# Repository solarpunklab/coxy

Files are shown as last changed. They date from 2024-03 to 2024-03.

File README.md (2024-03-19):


<div align="center">
<!-- ## SOLARPUNKLAB - CoXY -->
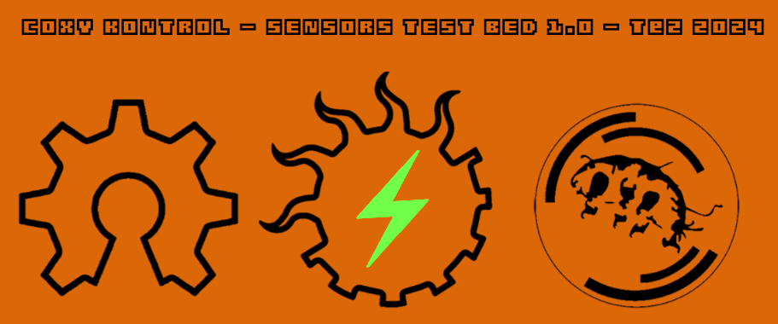
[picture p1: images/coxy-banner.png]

<!-- PROJECT LOGO -->

</div>

<br>

<div align="left" width = 90% id="contents">
<!-- TABLE OF CONTENTS -->
<details open>
  <summary style="background-color: #aaa;"><b>CONTENTS</b></summary>
  <ul>
	<li><a href="#about">About CoXY<br></a></li>
	<li><a href="#coxy-hardware">CoXY Hardware<br></a></li>
	<li><a href="#coxy-software">CoXY Sofwtare<br></a></li>
  </ul>
  </details>
</div>

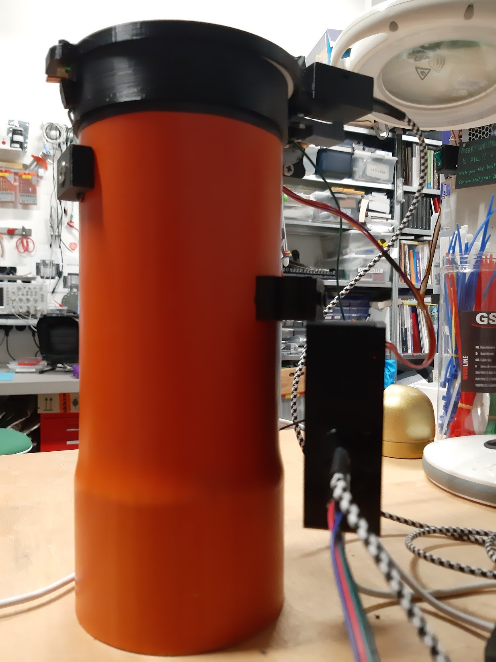
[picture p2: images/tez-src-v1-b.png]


<br><br><hr> <br><br>

<!-- >>>>>> TABLE ABOUT CoXY <<<<< -->
<table width = 90%>
<tr>
<td align = "justify" width = 90% colspan=2>
<p align="justify" id="about">
<b>ABOUT CoXY</b>
<br><br>
CoXY is a project by TeZ of 
<a href="http://solarpunklab.org">SOLARPUNK LAB</a> / 
<a href="http://hackteria.org">HACKTERIA</a> 
aimed at designing and experimenting a combined hardware and software platform that can function as a test bed for sensors' data monitoring/visualization and automation control, including motors, lights, switches and/or anything that can be driven by transistors. 
<br><br>
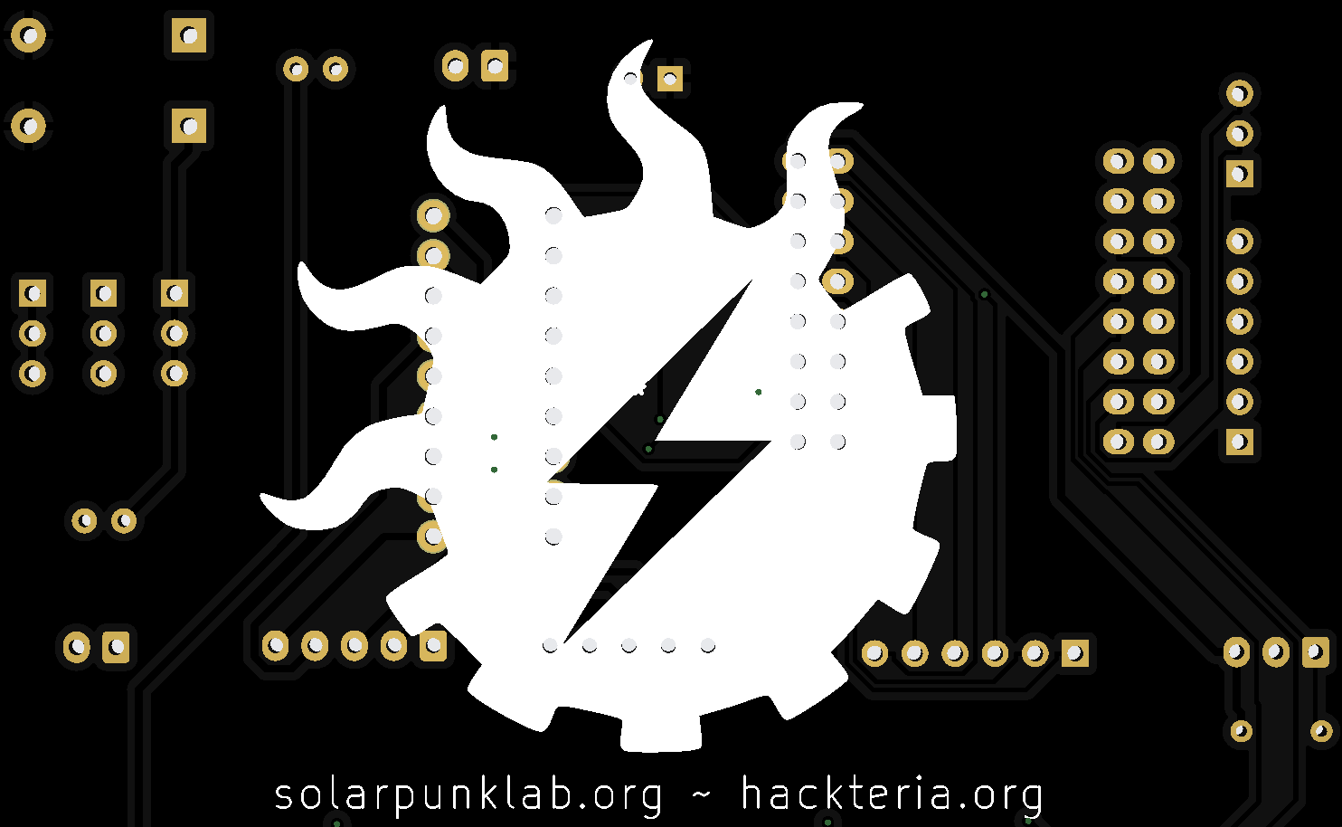
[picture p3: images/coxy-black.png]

<br><br>
The concept arose from the collaborative efforts of Marc Dusseiller Dusjagr  and Fernando Castro, both affiliated with HACKTERIA. Their inspiration stemmed from their involvement in the GOSH Open Hardware project, where they jointly explored the design and creation of a DIY platform for Soil Respiration Chamber(SRC). See <a href="https://hackteria.org/wiki/CO2_Soil_Respiration_Chamber">Hackteria Wiki</a> for an extended overview and documentation.
<br><br>
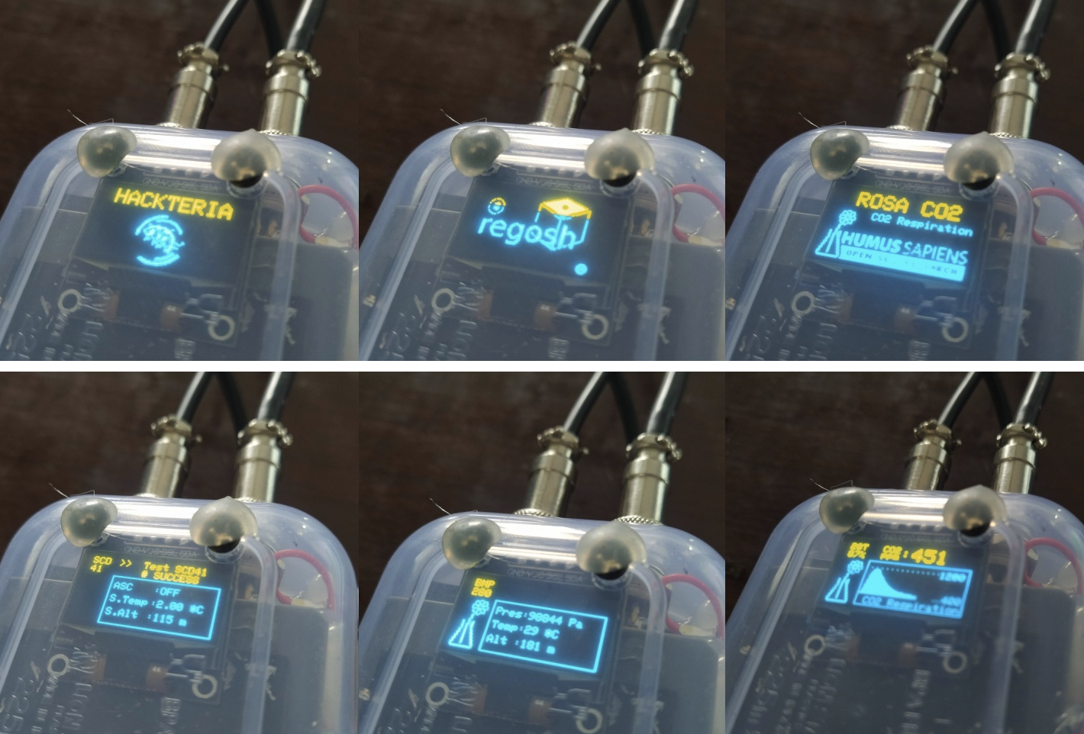
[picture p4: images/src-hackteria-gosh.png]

<br><br>
TeZ and Marc reconstructed a SRC prototype at Solarpunk Lab headquarters in Amsterdam. Subsequently, TeZ embarked on experimenting with an expanded version, aiming to incorporate local sensor data monitoring via WiFi/websockets technology and mechanical parts control using motors. 
<br><br>
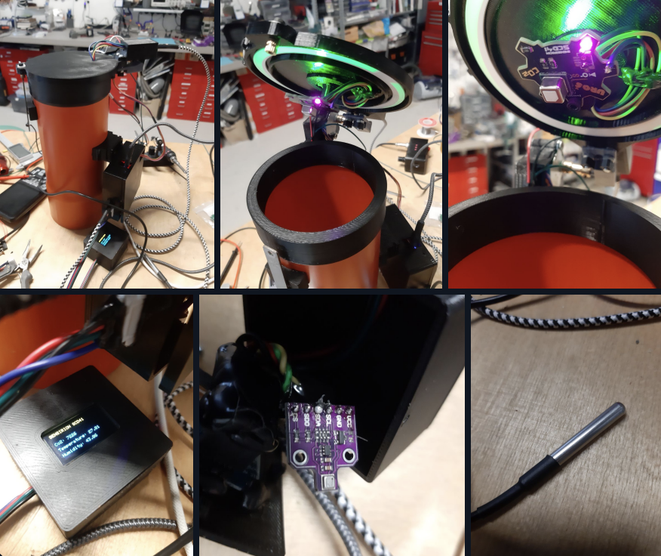
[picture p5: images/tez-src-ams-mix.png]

<br>
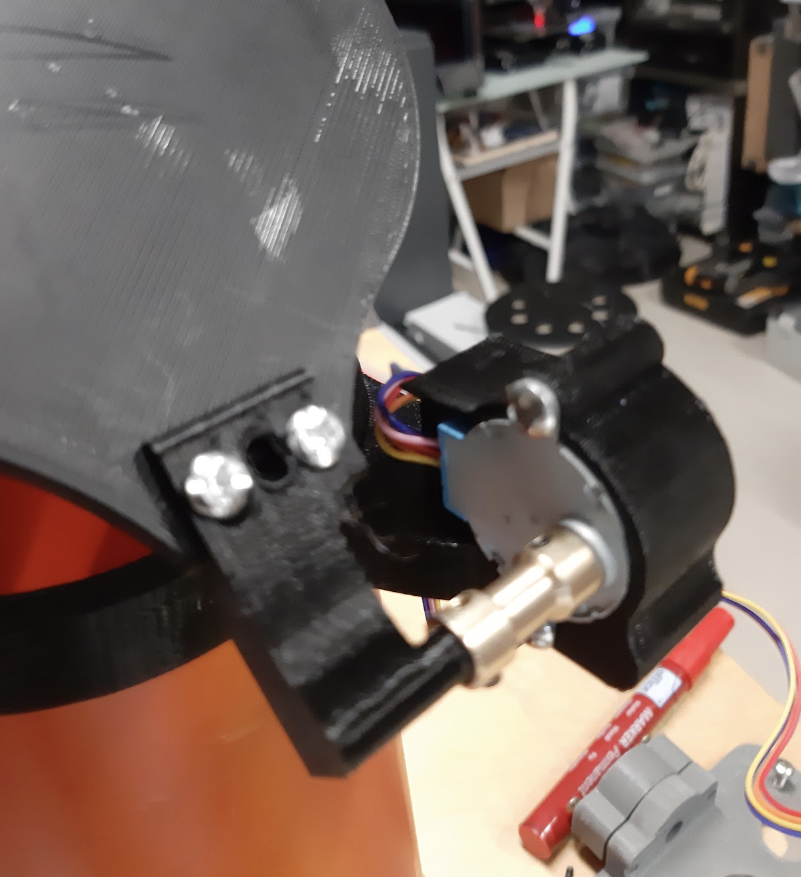
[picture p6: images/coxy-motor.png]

<br><br>
TeZ designed a printed circuit board (PCB) capable of seamlessly daisy-chaining up to five I2C devices. Additionally, it enables control over 8 channels of analog electrical signals via a transistor array IC. This is ideal to easily control the 2 coils of a 28byj-48 stepper motor with 4 channels. The PCB also features breakout options for additional ESP32 I/O pins and voltage supply.
<br><br>
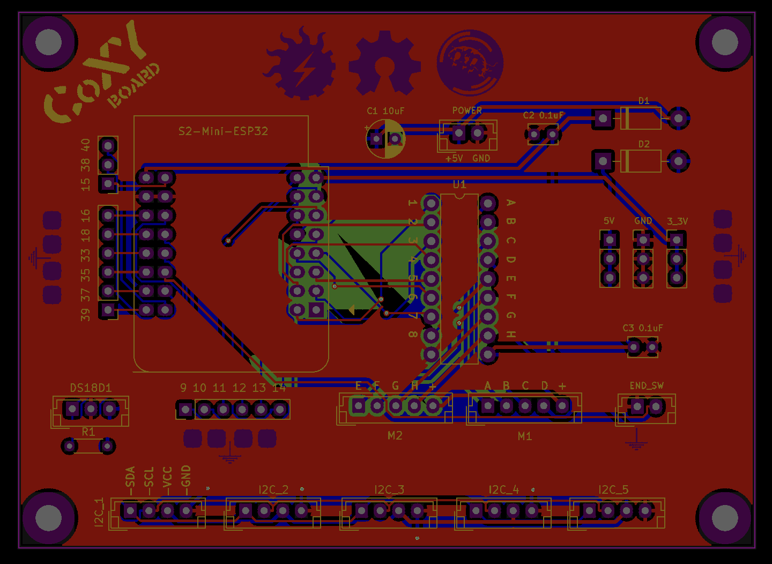
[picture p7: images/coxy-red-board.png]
</a>
This first version of the PCB is paired with a browser-based (hence cross-platform) software application, highly customizable and flexible.

<br><br>


<br><br>

<a href="#contents"></A>
<br>
</tr>
</table>

 <!-- >>>>>> TABLE CoXY HARDWARE <<<<< -->
<table width = 90%>
<tr>
<td align = "justify" width = 90% colspan=2>
<p align="justify" id="coxy-hardware">
<b>CoXY HARDWARE</b>
<br><br>
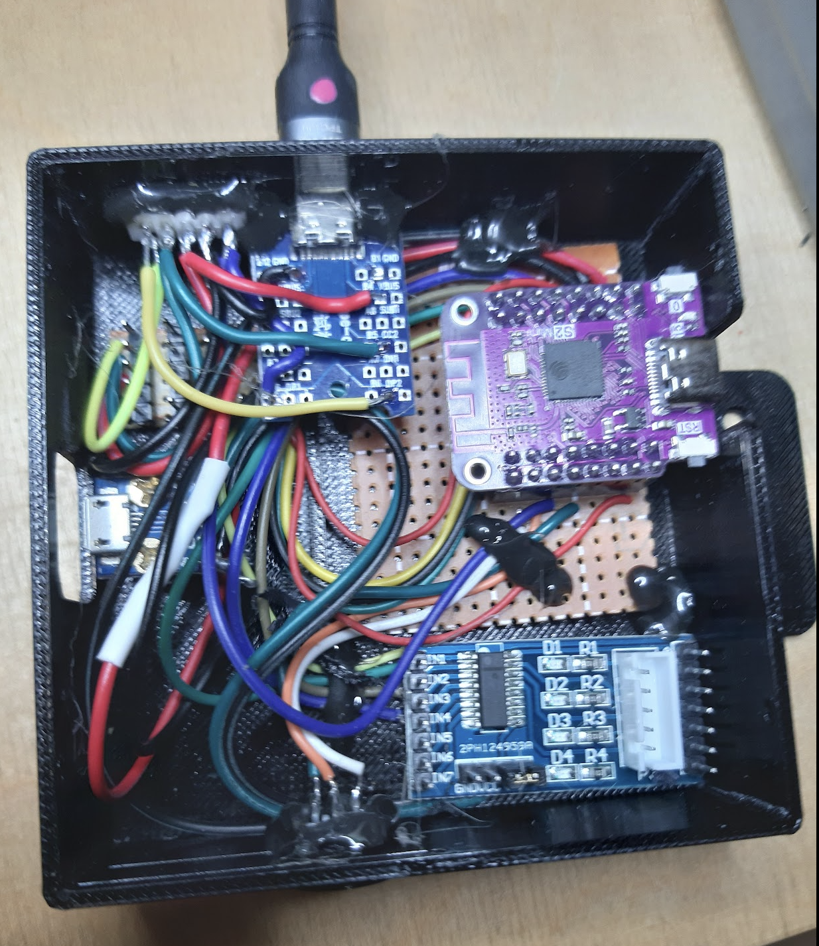
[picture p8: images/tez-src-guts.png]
</a>
<br>
first working proto board

CoXY's test bed consists of a Lolin S2 mini ESP32 board expander that can directly interface to a ULN2803 darlington trasistor array and to the I2C bus with five onboard channels. More S2 i/o pins are exposed to connect other analog or one-wire sensors and actuators.
<br><br>
While the CoXY board was designed to reproduce a setup for Soil Respiration Chamber(s), this circuit can facilitate all kind of projects that make use of up to five I2C peripherals and up to 8 low power transistor controlled devices. The adoption of Lolin S2 Mini ESP32 board is very advantageous for the minimal size of this microcontroller, its power, the many number of i/o pins and the very convenient price too.
<br><br>
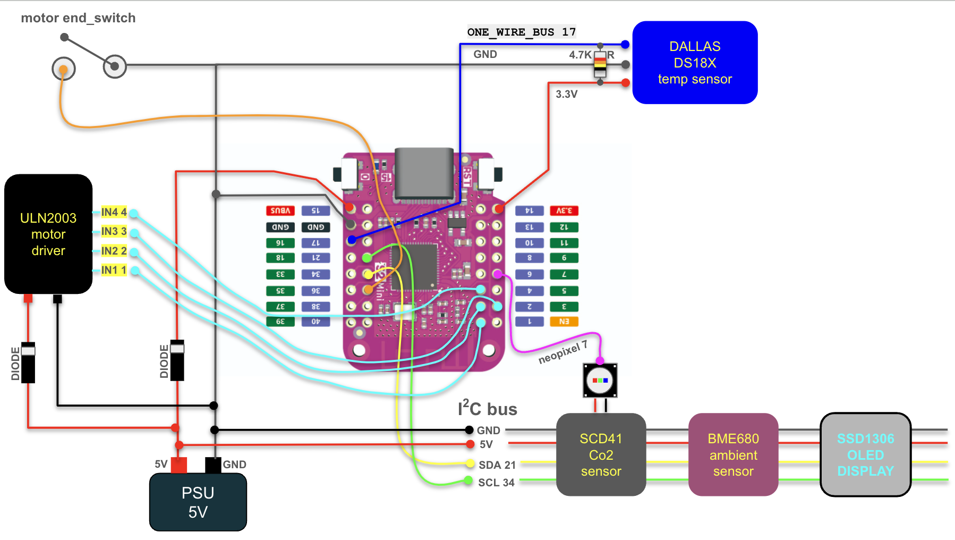
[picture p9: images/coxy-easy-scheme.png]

<br><br>
</tr>

<tr>

<td align = "left" width = 90% colspan=2>
<b>PARTS</b>
<br><br>
The test bed of choice for CoXY comprises:

<ul>
<li> Lolin S2 mini ESP32
<li> ULN2803 transistor array IC
<li> 28BYJ-48 stepper motor
<li> SENSIRION SCD41 - I2C Carbon Dioxide, temperature and humidity sensor
<li> BME680 - I2C temperature, humidity, pressure and gas sensor
<li> DALLAS DS18b20 "one-wire" Temperature sensor
<li> SSD1306 - 128x64 - I2C OLED display
</ul>

All parts are "optional" and can be excluded from the setup by simply commenting the #define statements in the main.cpp code. 
<br><br>
The <a href="https://github.com/GenericLab/UROS-CO2_brkout">UROS breakout</a> board was kindly provided by Marc to support the development of this project and it features also an optional connection to a NEOPIXEL rgb led unit.
<br><br>
Below all images and links to source the individual parts.
<br><br>
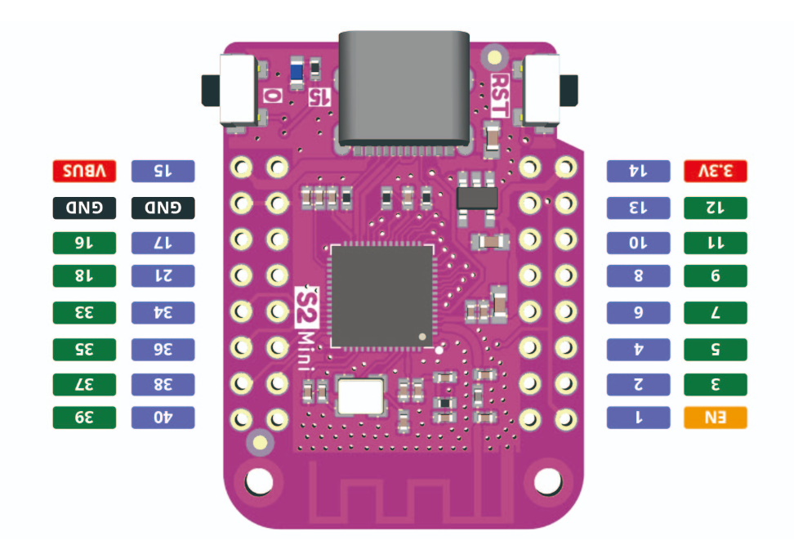
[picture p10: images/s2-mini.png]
<nr>
LOLIN S2 Mini ESP32
<br><br>
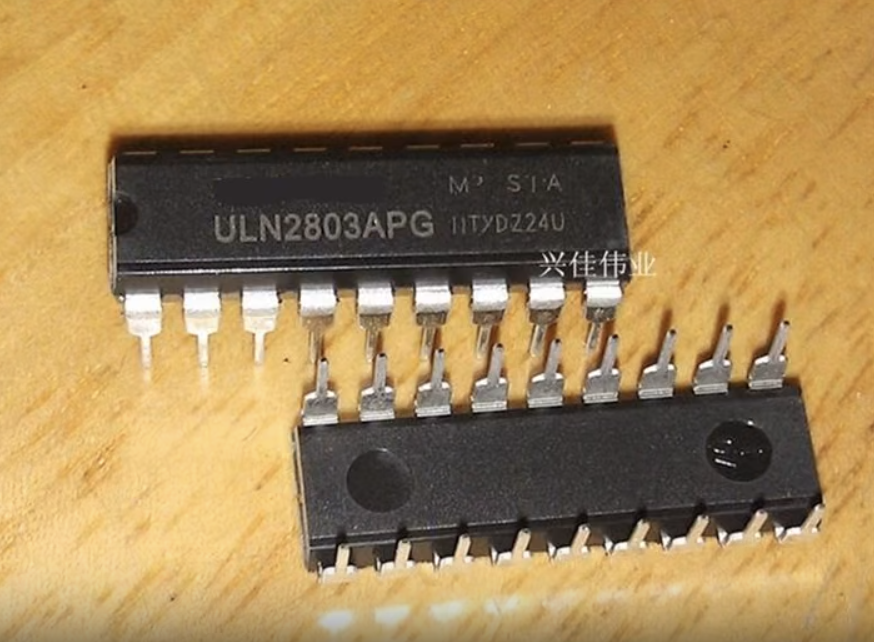
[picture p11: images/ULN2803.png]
<a href="https://nl.aliexpress.com/item/32461441516.html"><br>
ULN2803  - Bipolar (BJT) Transistor Array 8 NPN Darlington 50V 500mA </a>
<br><br>
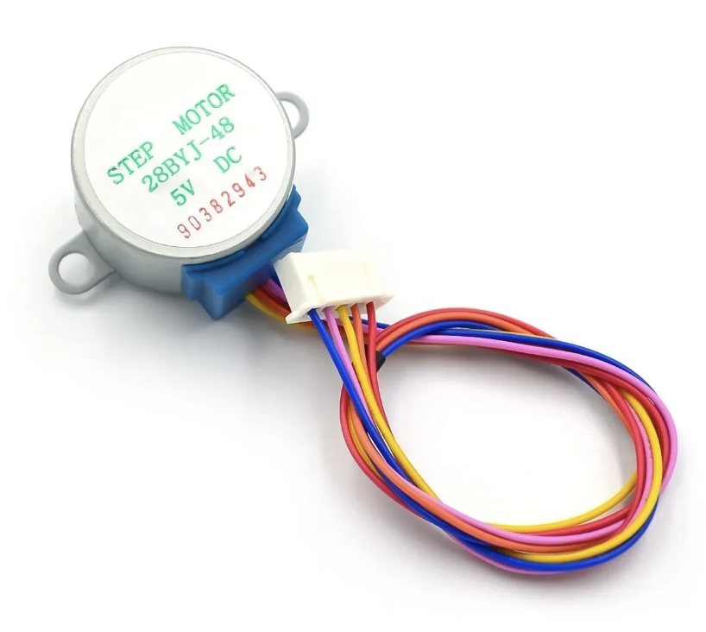
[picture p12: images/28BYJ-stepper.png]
<a href="https://nl.aliexpress.com/item/1005006141716201.html"><br>
28BYJ-48 5V stepper motor</a>
<br><br>
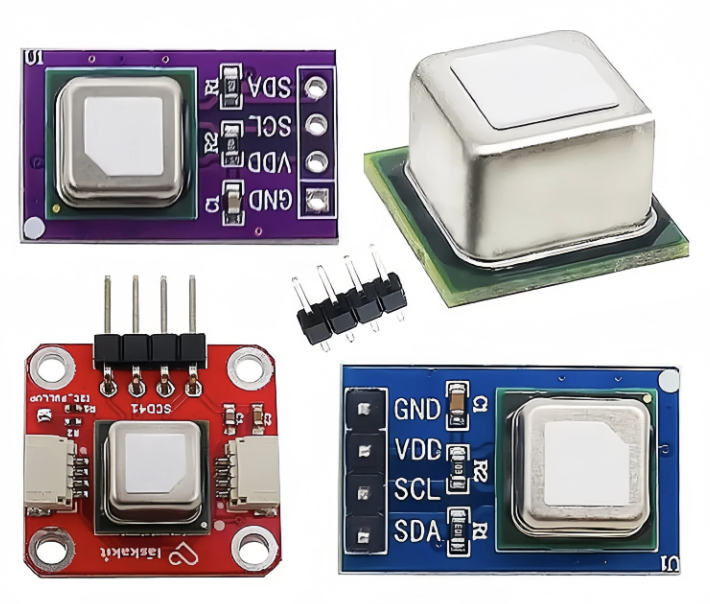
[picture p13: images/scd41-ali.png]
<a href="https://nl.aliexpress.com/item/1005006387743045.html"><br>
SCD41  I2C Carbon Dioxide, Temperature And Humidity sensor</a>
<br><br>
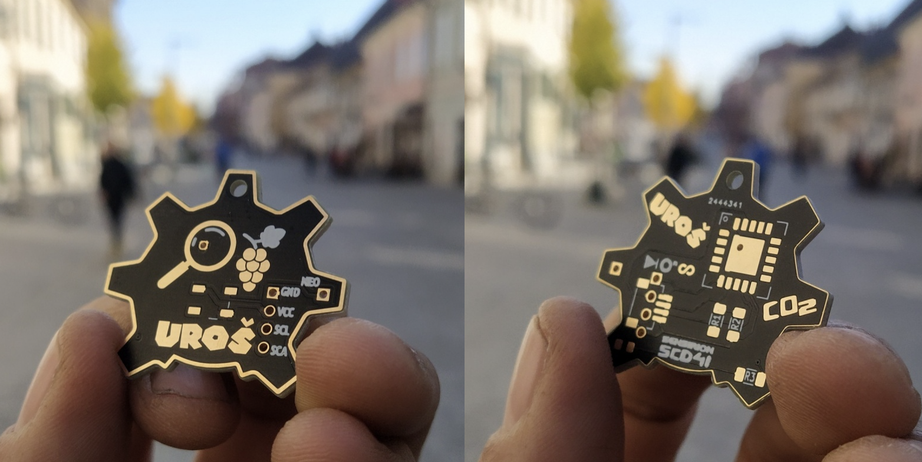
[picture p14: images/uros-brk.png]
<a href="https://github.com/GenericLab/UROS-CO2_brkout"><br>
first SCD41 UROS breakout</a>
<br><br>
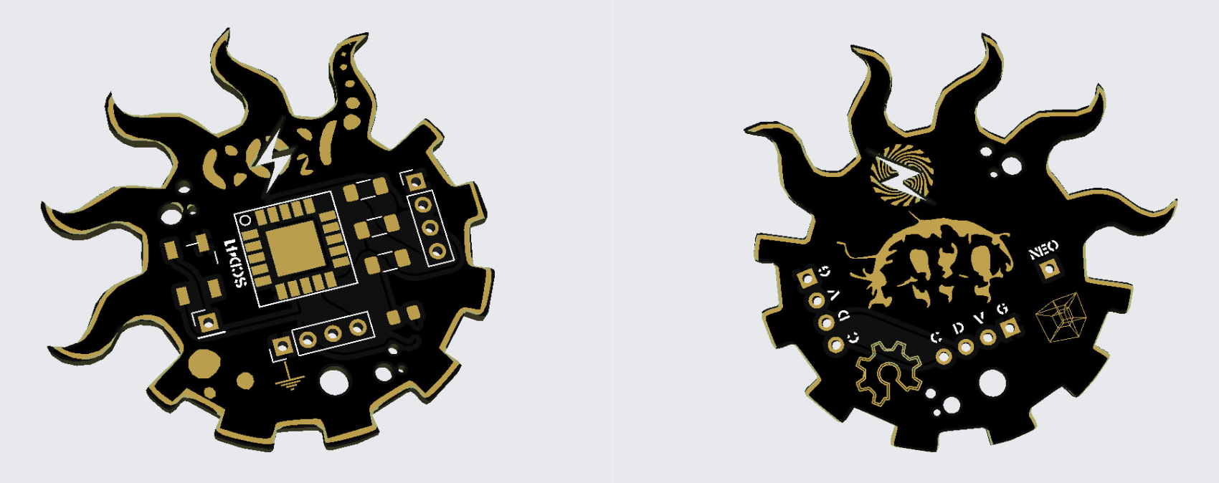
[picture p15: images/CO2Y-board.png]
<a href="https://github.com/solarpunklab/coxy/tree/main/PCB/CO2Y-brkout"><br>
 new SCD41 CO2Y breakout</a> designed by TeZ and Marc in 2024
<br><br>
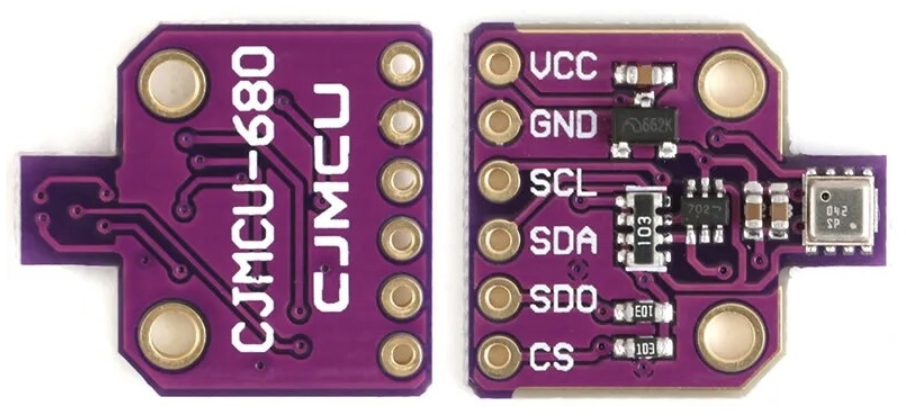
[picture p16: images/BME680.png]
<a href="https://nl.aliexpress.com/item/1005001602441073.html"><br>
BME680 Digital Temperature, Humidity, Pressure, Gas Sensor </a>
<br><br>

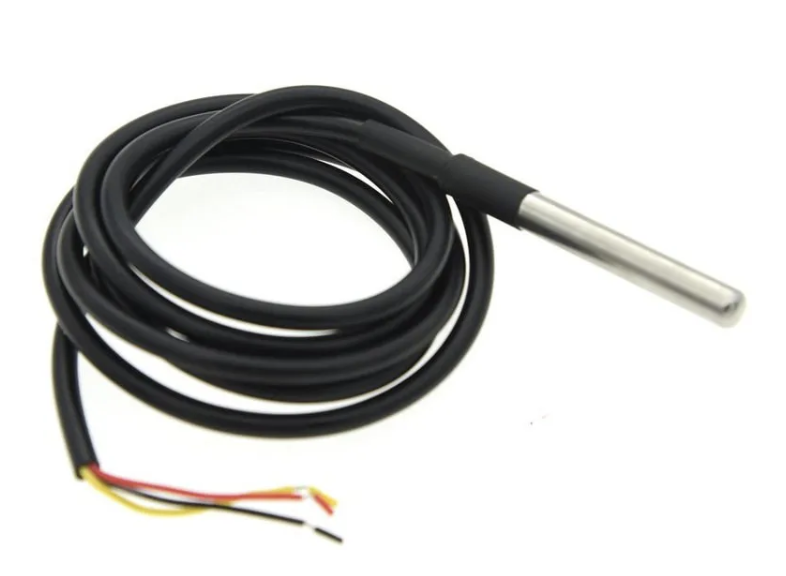
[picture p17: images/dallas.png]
<a href="https://nl.aliexpress.com/item/32676135779.html"><br>
DALLAS DS18b20 "one-wire" Temperature sensor</a>
<br><br>

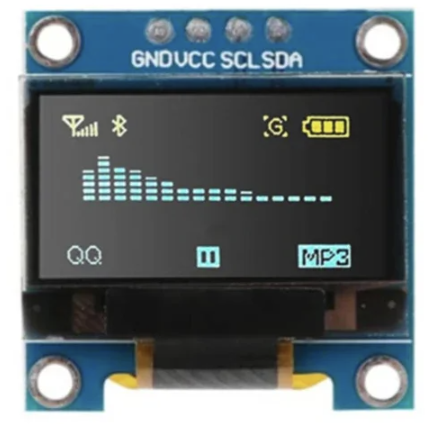
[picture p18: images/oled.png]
<a href="https://nl.aliexpress.com/item/1005006141235306.html"><br>
SSD1306 - 128x64 - I2C OLED display</a>
<br><br>

<hr>

CoXY BOARD is a PCB designed by TeZ and currently in testing phase. More details and photos will be published soon.

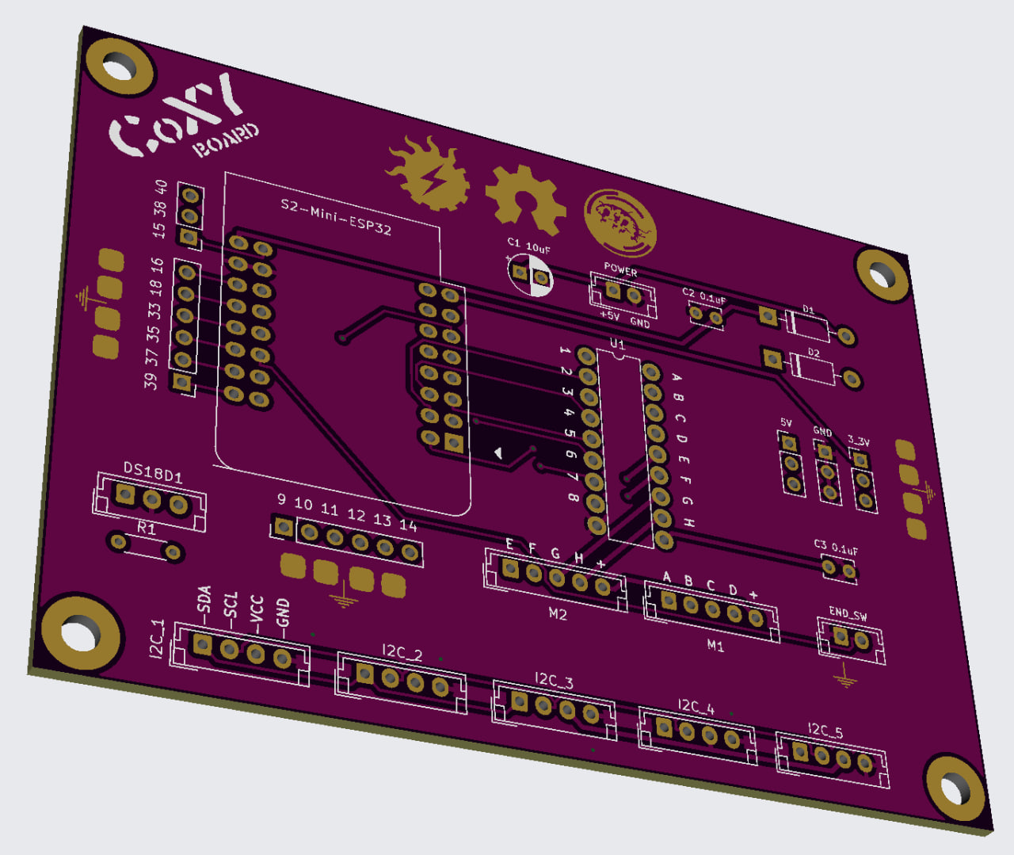
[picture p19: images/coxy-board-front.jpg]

<br>
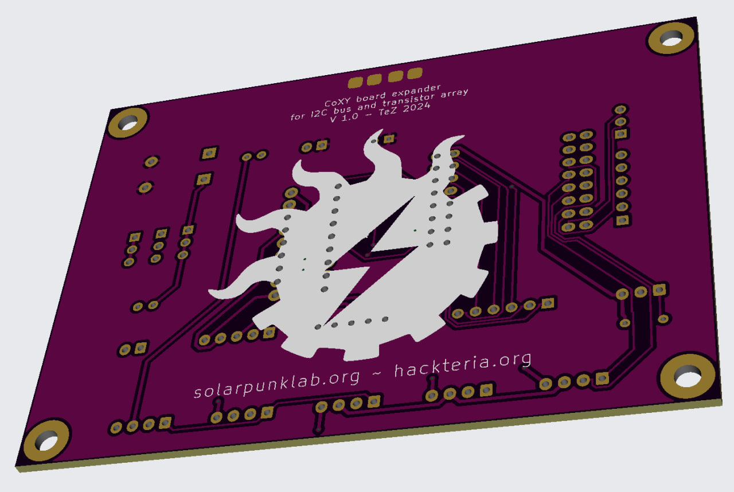
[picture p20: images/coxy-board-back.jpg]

<br>
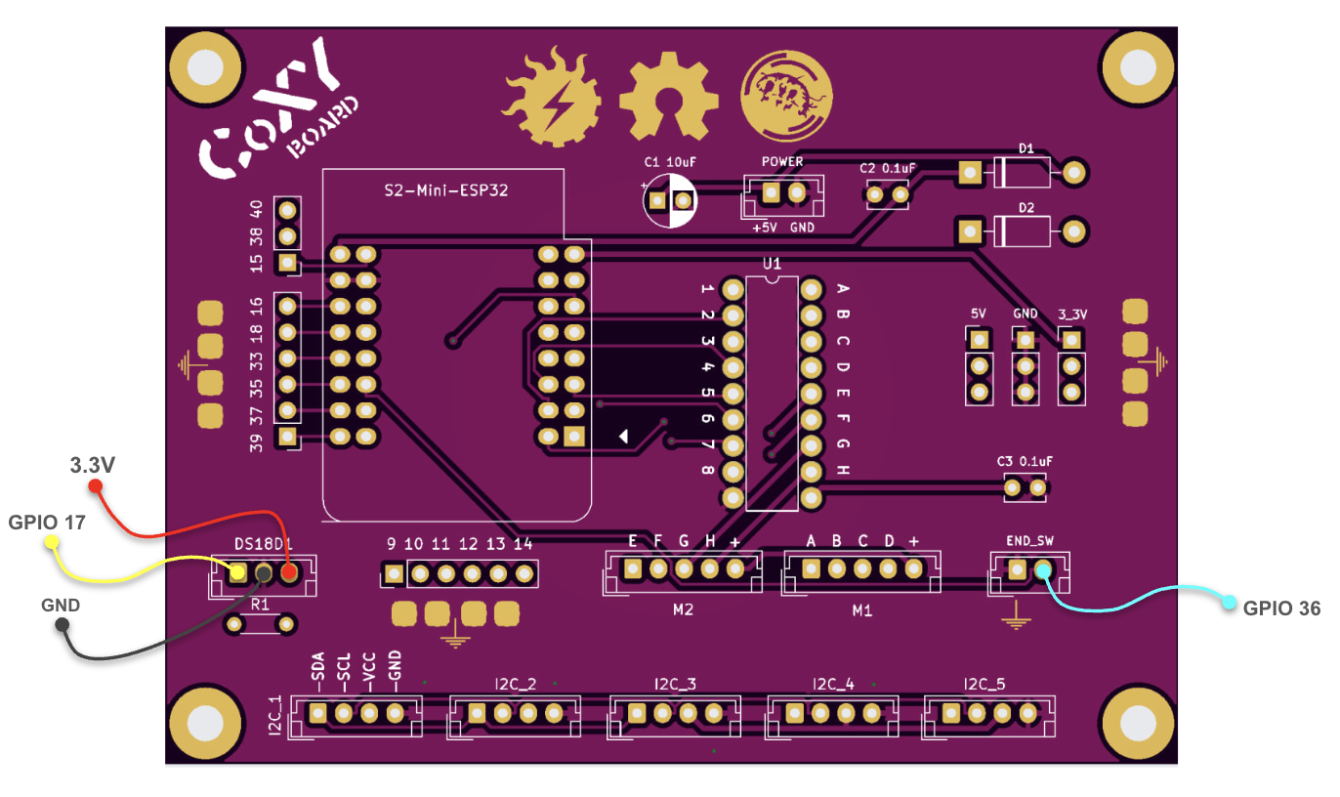
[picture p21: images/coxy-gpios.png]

<br><br>
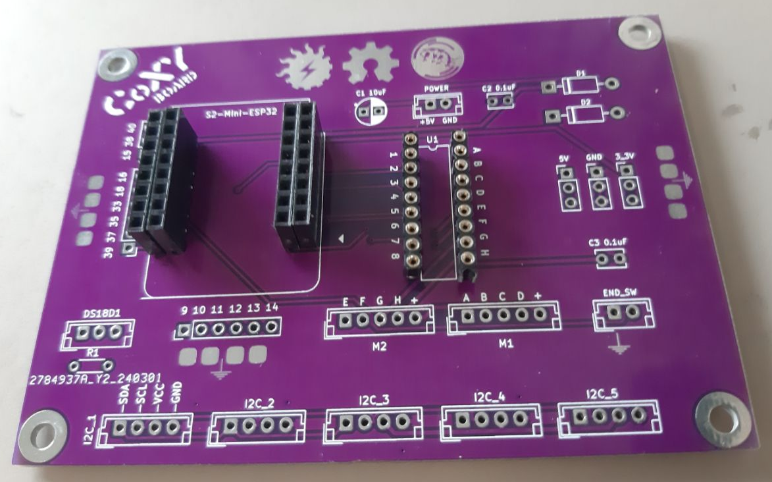
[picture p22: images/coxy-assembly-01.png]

<br><br>
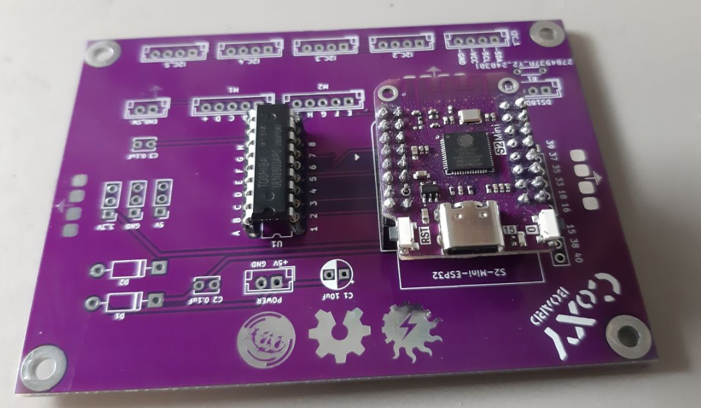
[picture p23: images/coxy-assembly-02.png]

<br><br>
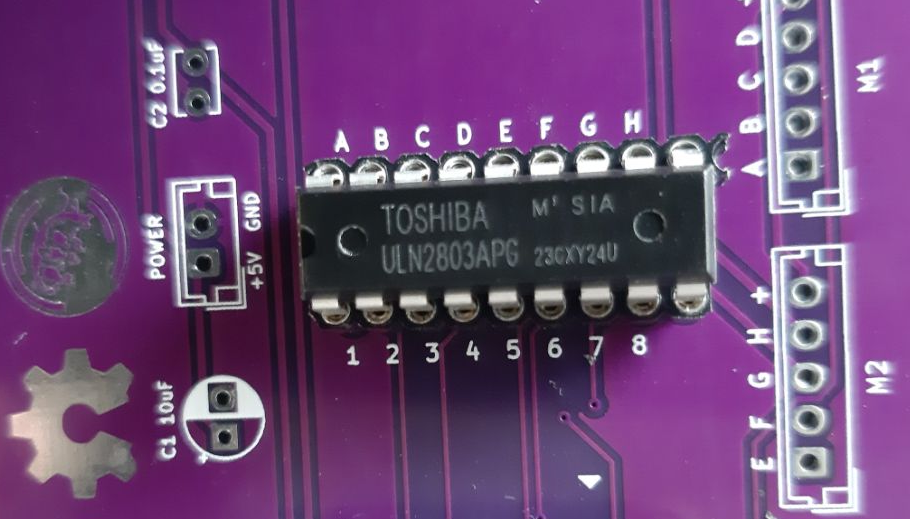
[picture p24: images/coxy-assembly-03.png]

<br><br>
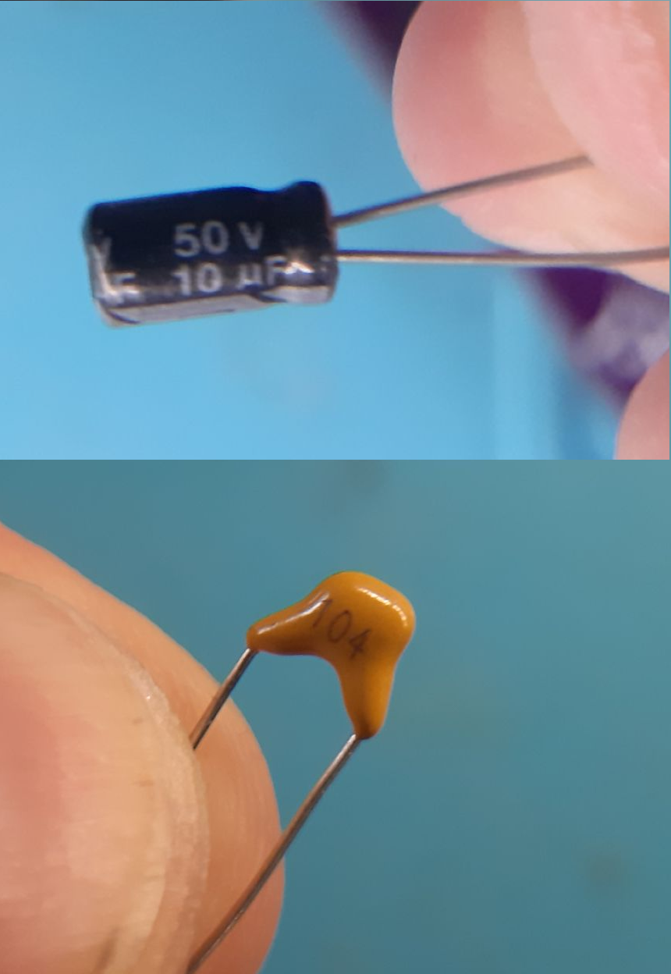
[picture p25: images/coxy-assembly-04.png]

<br><br>
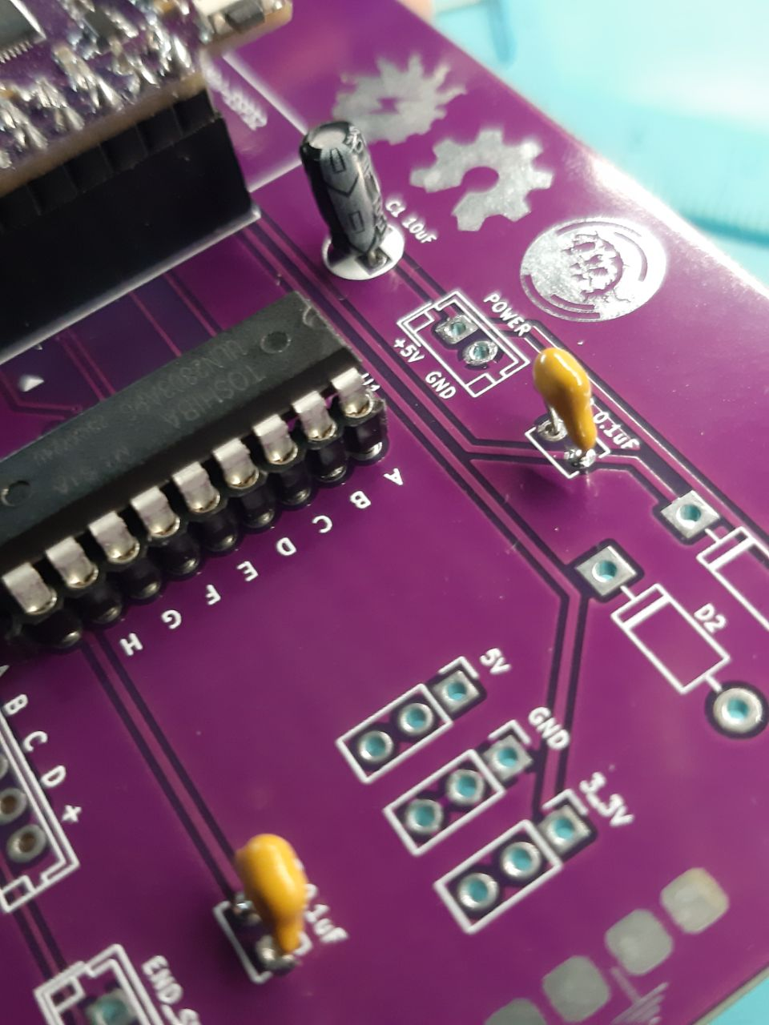
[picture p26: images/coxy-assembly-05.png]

<br><br>
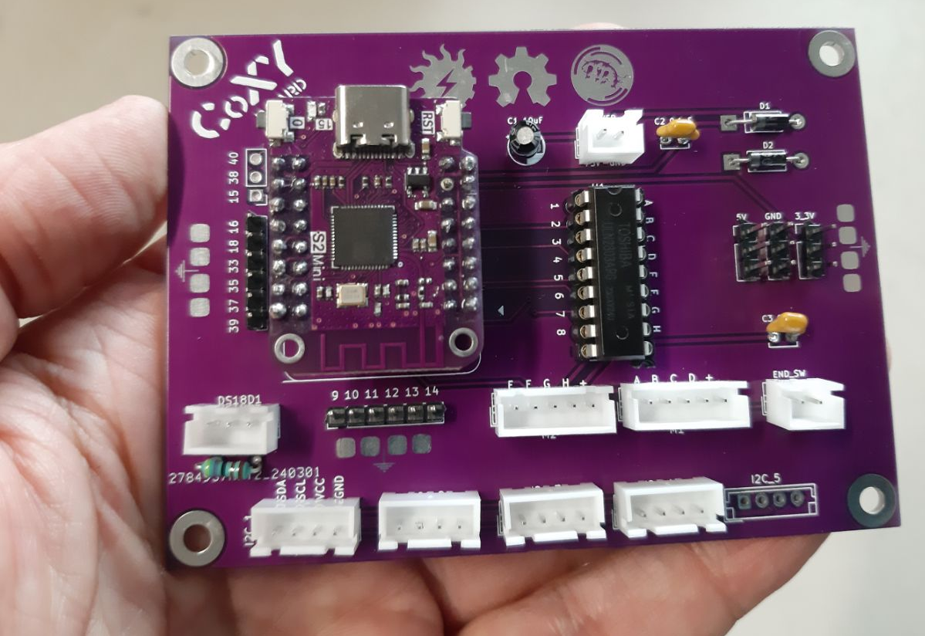
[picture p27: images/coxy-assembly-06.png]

<br>
<hr>
<br>
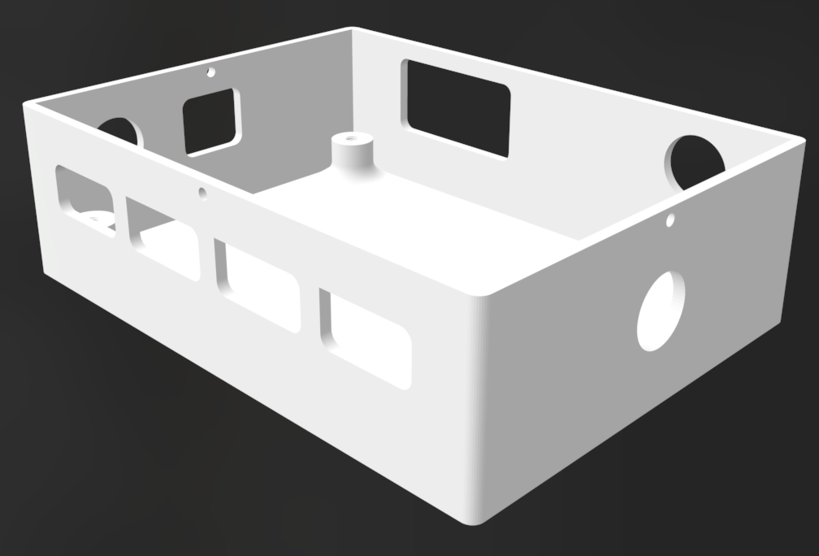
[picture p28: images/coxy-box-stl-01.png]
<a href="STL/CoxyBoxy.stl" target="3d"></A>
<br>
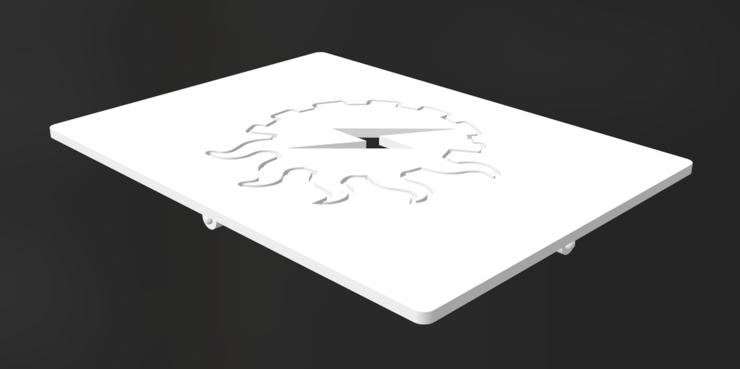
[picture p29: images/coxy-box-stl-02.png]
<a href="STL/CoxyBoxy-top.stl" target="3d"></A>
<br><br>
<a href="#contents"></A>
<br>

</td>
<br>
</tr>
</table>

<!-- >>>>>> TABLE CoXY SOFTWARE<<<<< -->
<table width = 90%>
<tr>
<td align = "justify" width = 90% colspan=2>
<p align="justify" id="coxy-software">
<b>CoXY SOFTWARE</b>
<br><br>
The CoXY KONTROL software is a web app served by the ESP32 developed as a combined Arduino C++, HTML5, Javascript, CSS and JSON code base. This browser-based app can therefore run on any device.
<br><br>
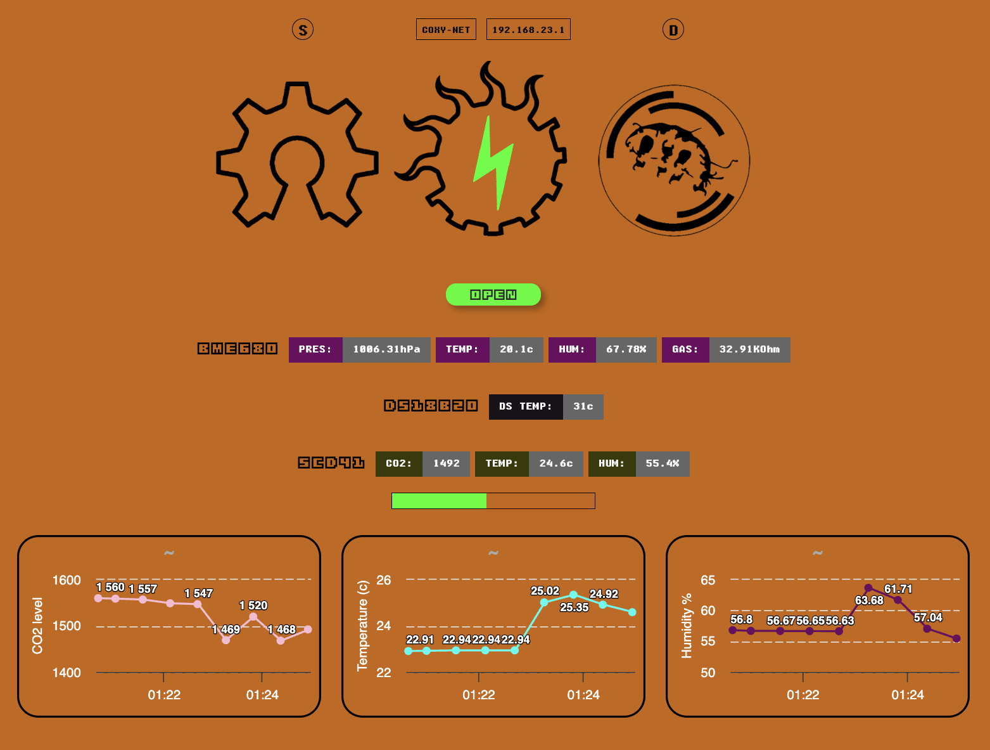
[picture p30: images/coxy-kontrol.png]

<br>
CoXY KONTROL dashboard
<br><br>
In order to simplify the simultaneous coding with different languages and many Arduino and Javascript libraries, VS-CODE / Platform IO was chosen as development environment. This way all the code base can be easily copied, edited and transferred at once without the need of re-configuration.
<br><br>
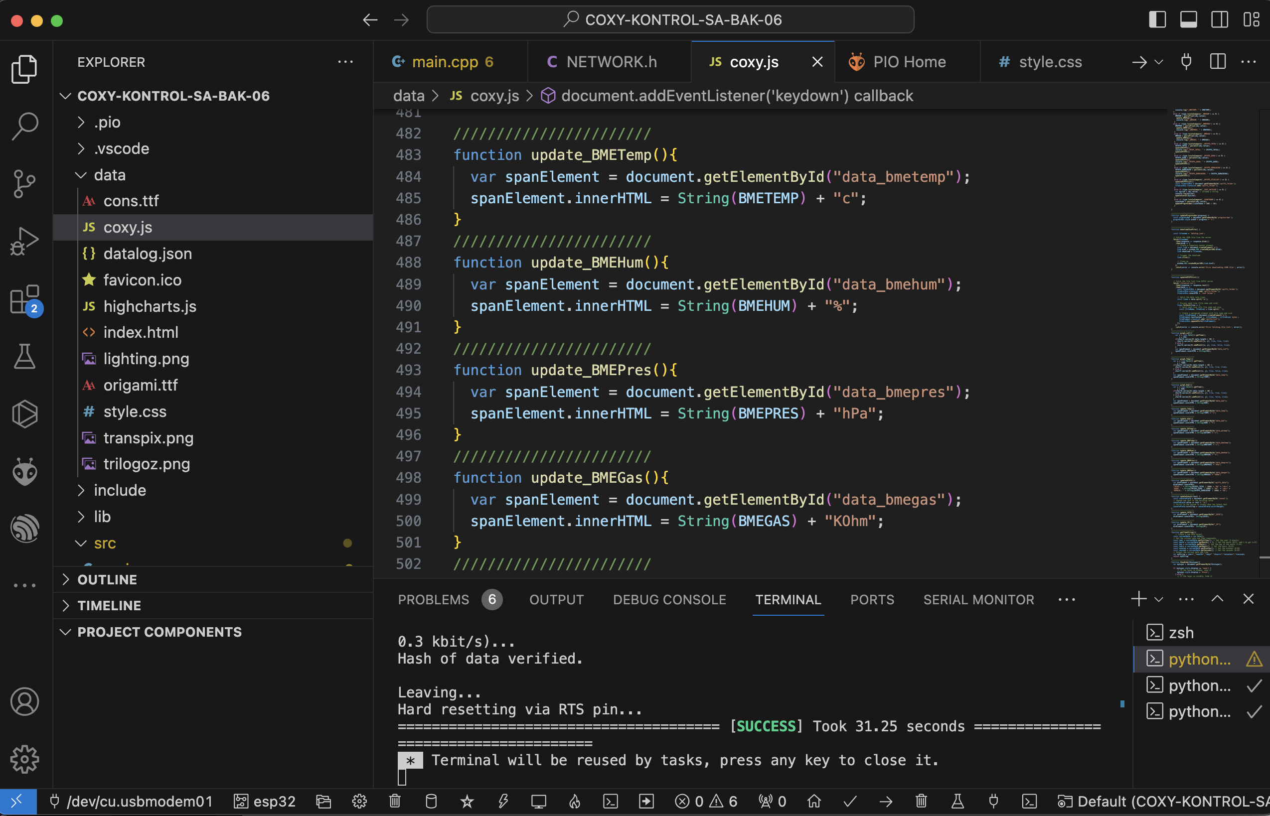
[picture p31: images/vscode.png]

<br>
VS-CODE environment
<br><br>
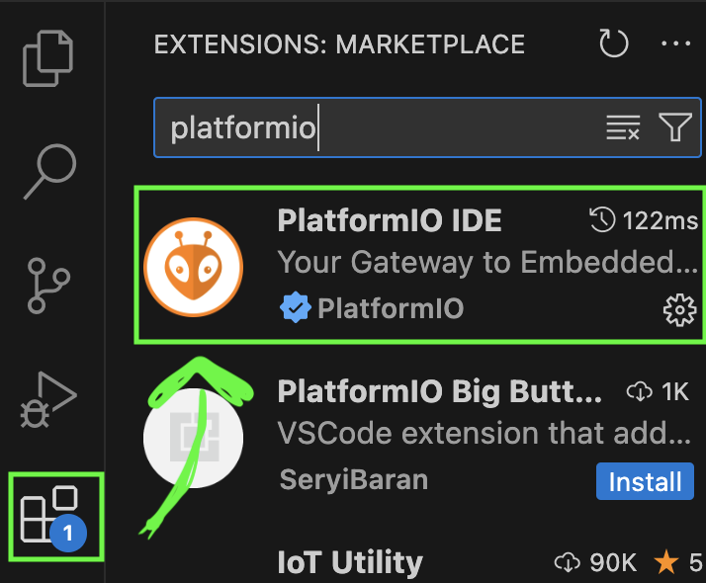
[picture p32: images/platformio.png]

<br>
Make sure you have PLATTFORMIO extension installed in your VS-CODE editor.
<br><br>
All files of this app are served (or created and stored in real-time) directly from the SPIFFS internal memory of the ESP32. That includes the main index.html page, the javascript code and libraries, css and json codes, images and fonts assets.
<br><br>
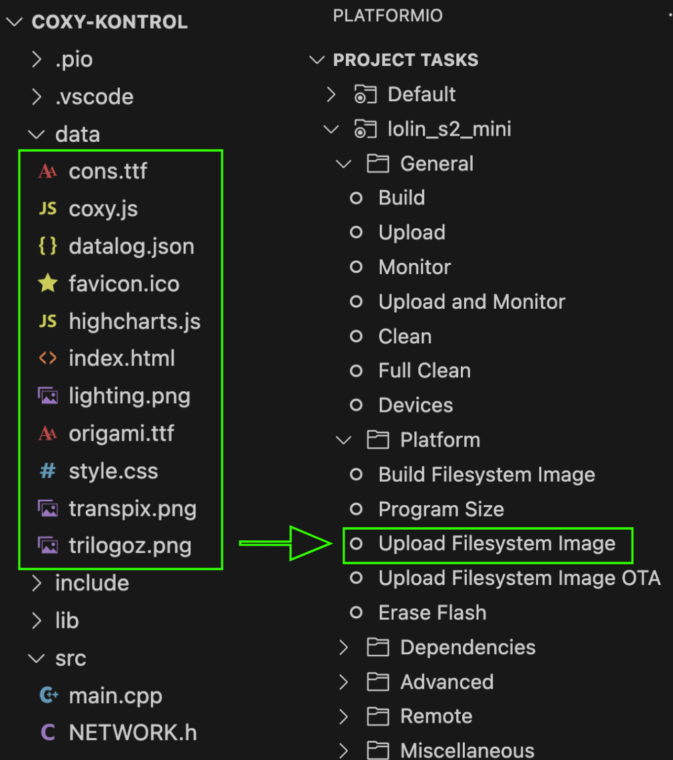
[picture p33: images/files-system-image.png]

<br><br>
In this application the SPIFFS files occupy about 1/3 ot the total available memory. 
<br><br>
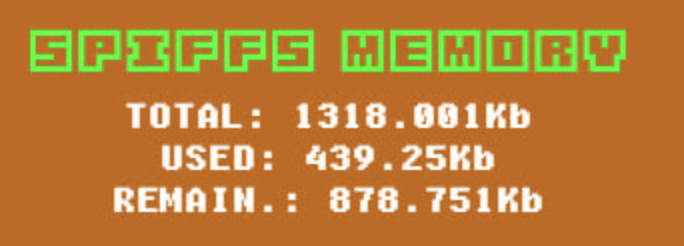
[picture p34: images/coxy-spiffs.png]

<br><br>
The esp32 sketch files "main.cpp" and "NETWORK.h" must be uploaded clicking on the arrow icon on the top right of VS-CODE window.
<br><br>
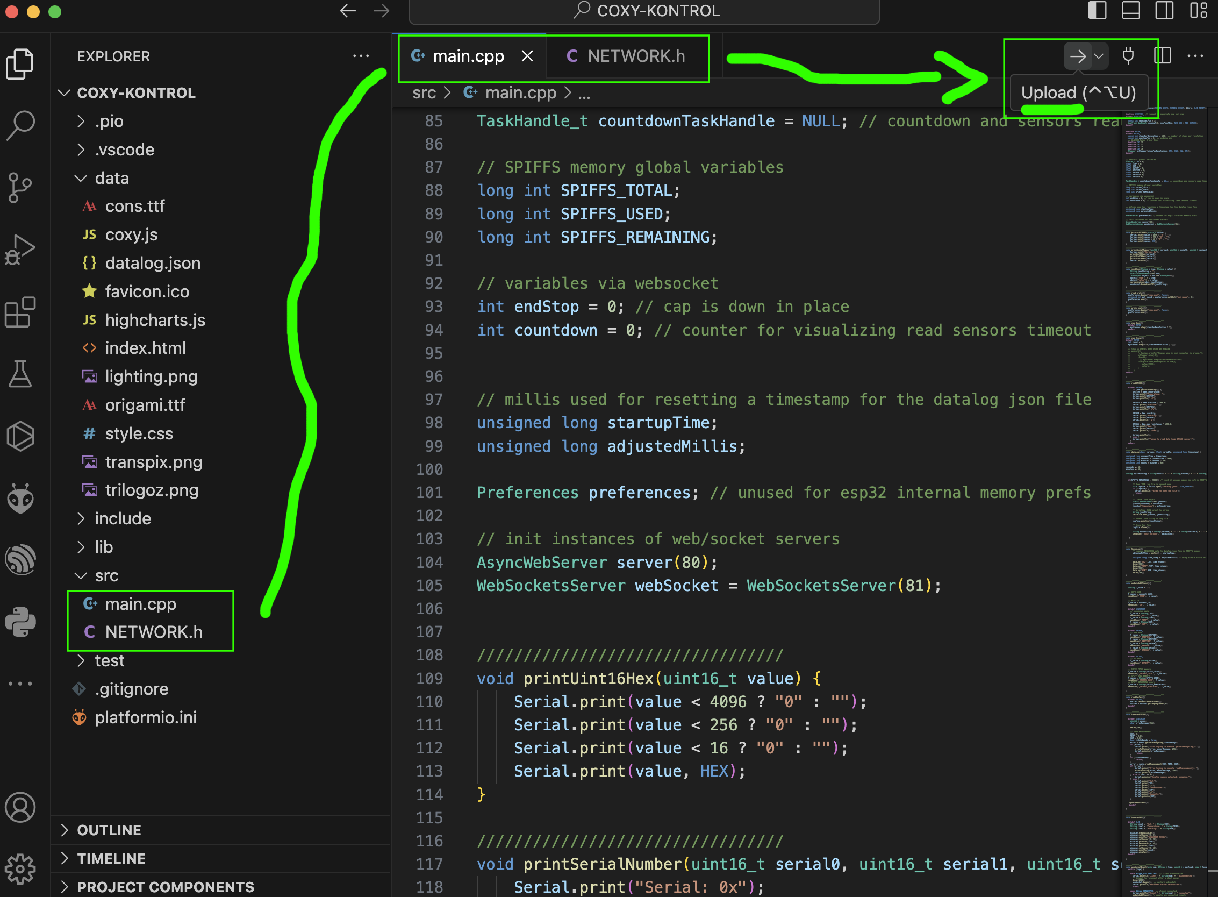
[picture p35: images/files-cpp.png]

<br><br>
Once SPIFFS and sketch files are uploaded to the ESP32, and the board has connected to a local WiFi network (or it has created its own "COXY-NET" access point) we can point our browser to the URL http://coxy.local
<br><br>

<br><br>
By clicking on the S icon or hitting the 's' key the SPIFFS memory popup will open to show that status of the spiffs internal memory and the currently stored and served files.
<br><br>
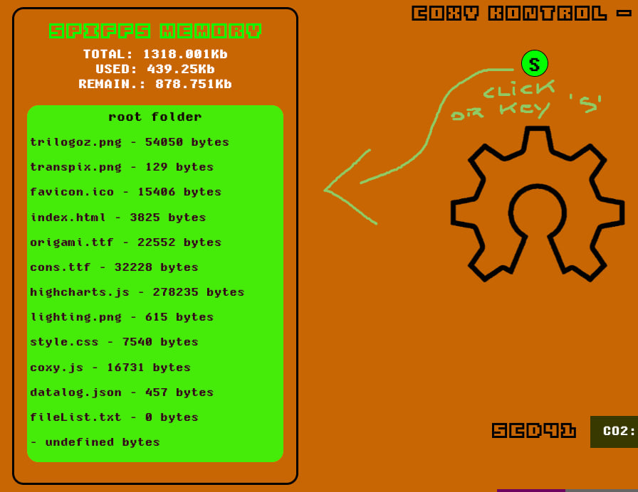
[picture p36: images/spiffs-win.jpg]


<br><br>
A reading is taken every 30 seconds from all sensors at once with a timeout callback.
A progress bar shows the countdown at each reading cycle.
<br><br>
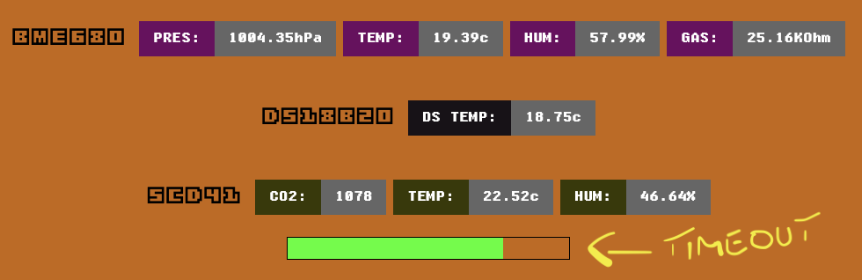
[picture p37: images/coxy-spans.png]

<br><br>
Data visualization is done via javascript on span elements for all sensors, except the SCD41's Co2 level, Temperature and Humidity that are shown via <a href="https://github.com/highcharts/highcharts">highcharts javascript library</a> featuring interactive data display.
<br><br>
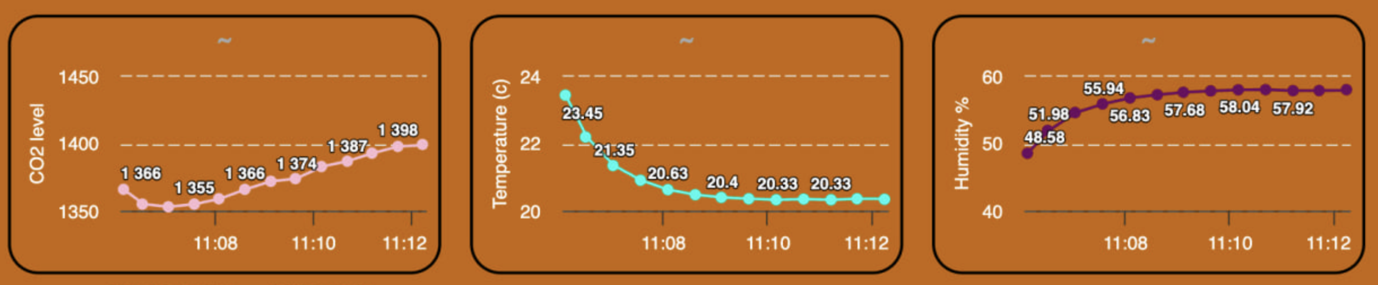
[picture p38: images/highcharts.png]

<br><br>
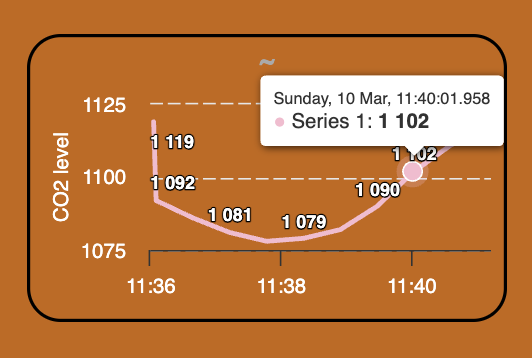
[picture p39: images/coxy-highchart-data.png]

<br><br>

<br><br>
A data log file with all the readings for the SCD41 is progressively saved in datalog.json file in the SPIFFS until the remaining inernal memory reaches a safety limit of 20kb. The json file can be downloaded locally by clicking on the datalog button.
<br><br>
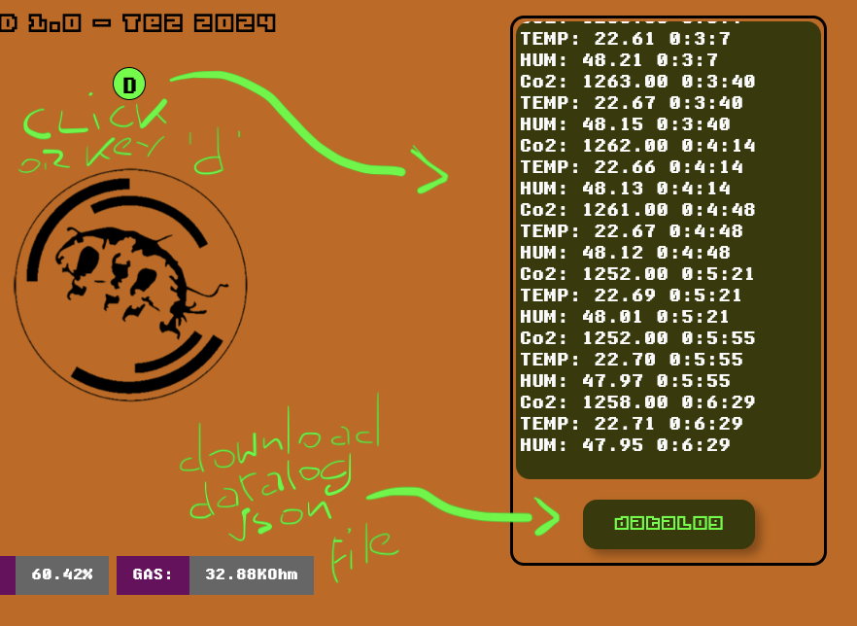
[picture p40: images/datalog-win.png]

<br><br>

<br>

<a href="#contents"></A>
<br>
</tr>
</table>

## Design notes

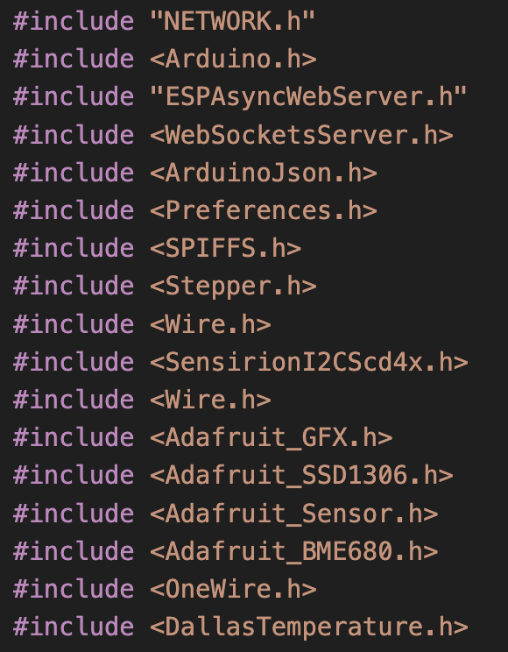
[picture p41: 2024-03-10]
images/code-include.png

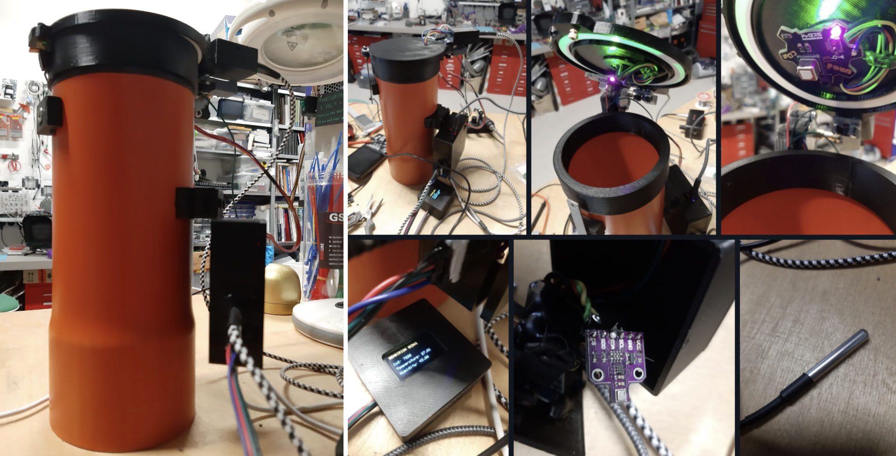
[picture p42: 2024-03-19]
images/wiki-coxy-01.png

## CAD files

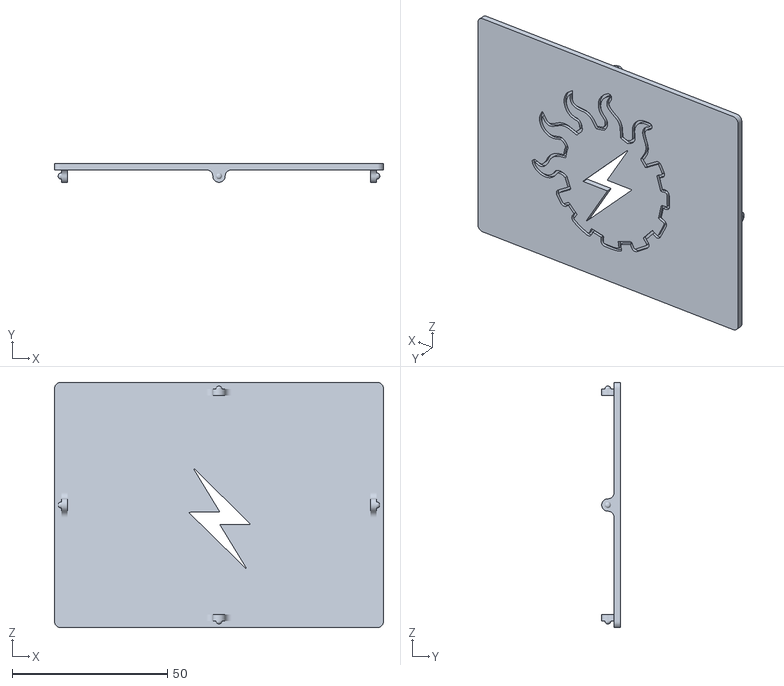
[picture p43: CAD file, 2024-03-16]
STL/CoxyBoxy-Top.stl
106.0 x 6.00 x 79.0

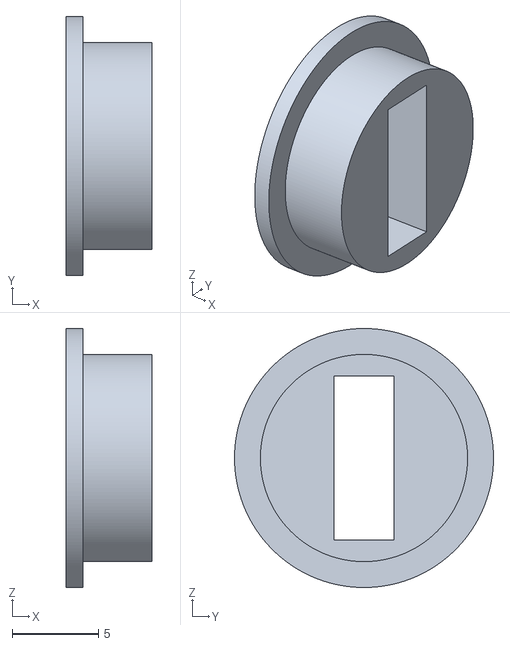
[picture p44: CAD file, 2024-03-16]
STL/USBC-12mm-Holder.stl
5.00 x 15.0 x 15.0

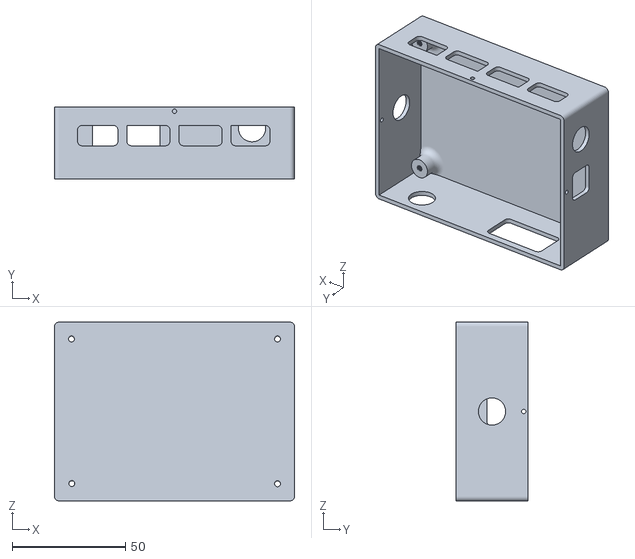
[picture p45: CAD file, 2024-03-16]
STL/CoxyBoxy.stl
106.0 x 32.0 x 79.0

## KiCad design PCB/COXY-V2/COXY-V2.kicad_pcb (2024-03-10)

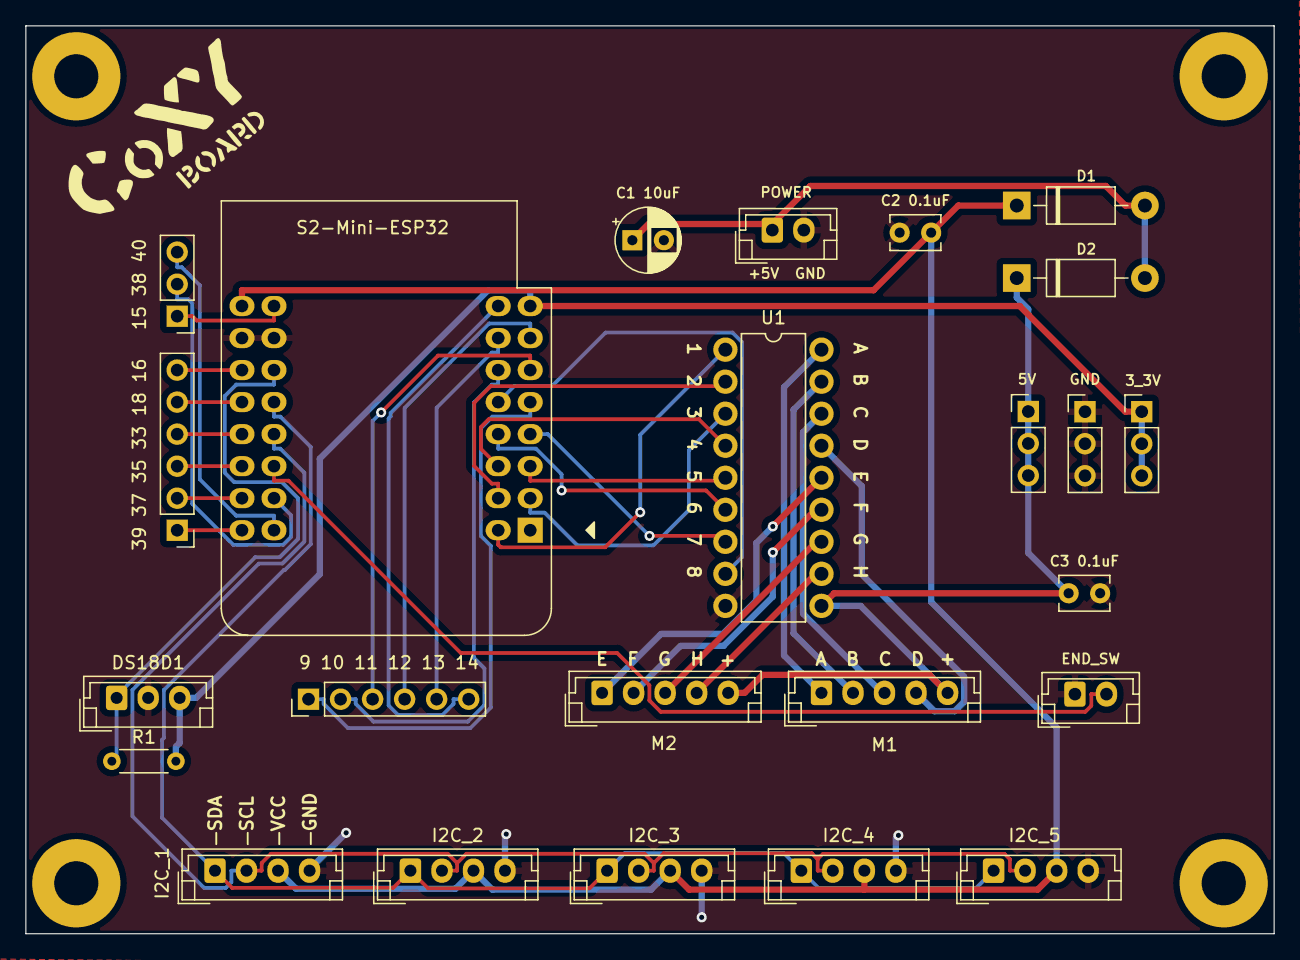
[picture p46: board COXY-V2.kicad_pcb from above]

Board: 2 copper layers, 99.0 x 72.0 mm, 39 parts (1 on the bottom side), 40 nets.

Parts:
3_3V, 5V, 15 38 40: Conn_01x03_Socket; PinHeader_1x03_P2.54mm_Vertical
4pad_1, 4pad_2, 4pad_2#2, 4pad_3: LOGO; 4pds
9 10 11 12 13 14, 39 37 35 33 18 16: Conn_01x06_Socket; PinHeader_1x06_P2.54mm_Vertical
C1 10uF: C 10uF; CP_Radial_D5.0mm_P2.50mm
C2 0.1uF: C 01uF; C_Disc_D3.8mm_W2.6mm_P2.50mm
C3 0.1uF: C 0.1uF; C_Disc_D3.8mm_W2.6mm_P2.50mm
D1, D2: 1N4001; D_DO-41_SOD81_P10.16mm_Horizontal
DS18D1: Conn_01x03_Socket; JST_EH_B3B-EH-A_1x03_P2.50mm_Vertical
END_SW: Conn_01x02_Socket; JST_EH_B2B-EH-A_1x02_P2.50mm_Vertical
GND: Conn_01x03_Socket; PinHeader_1x03_P2.54mm_Vertical
Gn1, Gn2, Gn3: LOGO; ground-logo-mask
Gnd4: LOGO; ground-logo-mask
H1, H2, H3, H4: MountingHole; MountingHole_3.5mm_Pad
HACKTERIA: LOGO; hackteria-logo-mask
I2C_1, I2C_2, I2C_3, I2C_4, I2C_5: Conn_01x04_Socket; JST_EH_B4B-EH-A_1x04_P2.50mm_Vertical
M1, M2: Conn_01x05_Socket; JST_EH_B5B-EH-A_1x05_P2.50mm_Vertical
OSH: LOGO; osh-logo-mask
POWER: Conn_01x02_Socket; JST_EH_B2B-EH-A_1x02_P2.50mm_Vertical
R1: 4.7K; R_Axial_DIN0204_L3.6mm_D1.6mm_P5.08mm_Horizontal
S2-Mini-ESP32: LOLIN Wemos S2 Mini
SPL: LOGO; spl-logo-mask
U1: ULN2803A

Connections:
+5V: C1 10uF.1, D1.2 (A), D2.2 (A), POWER.1
DSPIN: DS18D1.1, R1.1, S2-Mini-ESP32.30 (GPIO17)
ENDSW: END_SW.2, S2-Mini-ESP32.27 (GPIO36)
GND: C1 10uF.2, C2 0.1uF.1, C3 0.1uF.2, DS18D1.2, END_SW.1, GND.1, GND.2, GND.3, I2C_1.4, I2C_2.4, I2C_3.4, I2C_4.4, I2C_5.4, POWER.2, S2-Mini-ESP32.23 (GND), S2-Mini-ESP32.31 (GND), U1.9 (GND)
IO1: S2-Mini-ESP32.9 (GPIO1), U1.1 (I1)
IO2: S2-Mini-ESP32.10 (GPIO2), U1.2 (I2)
IO3: S2-Mini-ESP32.2 (GPIO3), U1.3 (I3)
IO4: S2-Mini-ESP32.11 (GPIO4), U1.4 (I4)
IO5: S2-Mini-ESP32.3 (GPIO5), U1.5 (I5)
IO6: S2-Mini-ESP32.12 (GPIO6), U1.6 (I6)
IO7: S2-Mini-ESP32.4 (GPIO7), U1.7 (I7)
IO8: S2-Mini-ESP32.13 (GPIO8), U1.8 (I8)
IO9: 9 10 11 12 13 14.1, S2-Mini-ESP32.5 (GPIO9)
IO10: 9 10 11 12 13 14.2, S2-Mini-ESP32.14 (GPIO10)
IO11: 9 10 11 12 13 14.3, S2-Mini-ESP32.6 (GPIO11)
IO12: 9 10 11 12 13 14.4, S2-Mini-ESP32.7 (GPIO12)
IO13: 9 10 11 12 13 14.5, S2-Mini-ESP32.15 (GPIO13)
IO14: 9 10 11 12 13 14.6, S2-Mini-ESP32.16 (GPIO14)
IO15: 15 38 40.1, S2-Mini-ESP32.32 (GPIO15)
IO16: 39 37 35 33 18 16.6, S2-Mini-ESP32.22 (GPIO16)
IO18: 39 37 35 33 18 16.5, S2-Mini-ESP32.21 (GPIO18)
IO33: 39 37 35 33 18 16.4, S2-Mini-ESP32.20 (GPIO33)
IO35: 39 37 35 33 18 16.3, S2-Mini-ESP32.19 (GPIO35)
IO37: 39 37 35 33 18 16.2, S2-Mini-ESP32.18 (GPIO37)
IO38: 15 38 40.2, S2-Mini-ESP32.26 (GPIO38)
IO39: 39 37 35 33 18 16.1, S2-Mini-ESP32.17 (GPIO39)
IO40: 15 38 40.3, S2-Mini-ESP32.25 (GPIO40)
SCL: I2C_1.2, I2C_2.2, I2C_3.2, I2C_4.2, I2C_5.2, S2-Mini-ESP32.28 (GPIO34)
SDA: I2C_1.1, I2C_2.1, I2C_3.1, I2C_4.1, I2C_5.1, S2-Mini-ESP32.29 (GPIO21)
ULNOUT1: M1.1, U1.18 (O1)
ULNOUT2: M1.2, U1.17 (O2)
ULNOUT3: M1.3, U1.16 (O3)
ULNOUT4: M1.4, U1.15 (O4)
ULNOUT5: M2.1, U1.14 (O5)
ULNOUT6: M2.2, U1.13 (O6)
ULNOUT7: M2.3, U1.12 (O7)
ULNOUT8: M2.4, U1.11 (O8)
VBUS1: C2 0.1uF.2, D1.1 (K), I2C_1.3, I2C_2.3, I2C_3.3, I2C_4.3, I2C_5.3, S2-Mini-ESP32.24 (VBUS)
VBUS2: 5V.1, 5V.2, 5V.3, C3 0.1uF.1, D2.1 (K), M1.5, M2.5, U1.10 (COM)
VBUS3_3: 3_3V.1, 3_3V.2, 3_3V.3, DS18D1.3, R1.2, S2-Mini-ESP32.8 (3_3V)

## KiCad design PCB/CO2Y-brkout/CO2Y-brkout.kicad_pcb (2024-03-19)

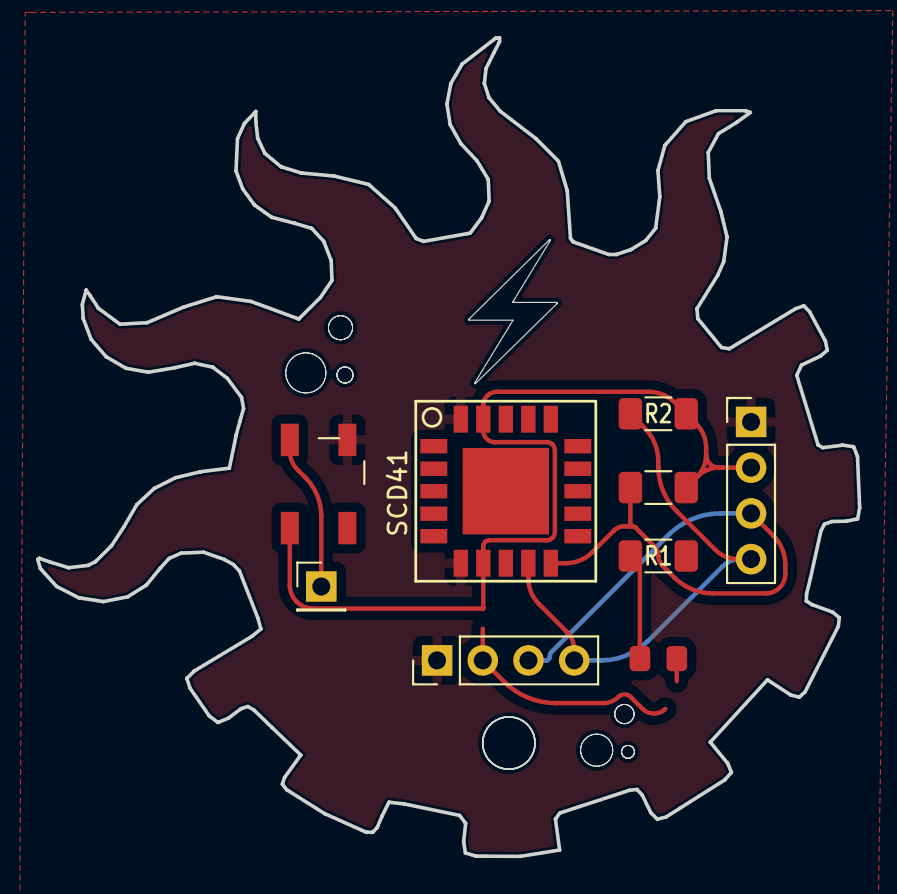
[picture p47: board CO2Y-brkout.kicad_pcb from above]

Board: 2 copper layers, 45.7 x 45.5 mm, 14 parts (0 on the bottom side), 6 nets.

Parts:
D1: LED; LED_0805_HandSolder
D2: WS2812B; NEO-Pixel_WS2812B
J1: Conn_01x01_Pin; PinHeader_1x01_P2.54mm_Vertical
J2, J3: Conn_01x04; PinHeader_1x04_P2.54mm_Vertical
R1, R2, R3: 10k; R_1206_HandSolder
SENSIRION: LOGO; spl-outline-board
U1: SCD41; SCD41_Ada
graf2, graf3: LOGO; gas-particles-1
graf4: LOGO; CO2Y
graf5: LOGO; bubbles

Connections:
GND: D2.3 (VSS), J2.1, J3.1, R1.2, U1.6 (VSS@1), U1.20 (VSS@2)
NEO_IN: D2.4 (DIN), J1.1
unnamed: D1.1 (K), R1.1
SCL: J2.4, J3.4, R2.1, U1.9 (SCL)
SDA: J2.3, J3.3, R3.1, U1.10 (SDA)
VCC: D1.2 (A), D2.1 (VDD), J2.2, J3.2, R2.2, R3.2, U1.7 (VDD), U1.19 (VDDH)

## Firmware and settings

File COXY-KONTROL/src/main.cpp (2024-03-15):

#include "NETWORK.h"   
#include <Arduino.h>
#include "ESPAsyncWebServer.h"
#include <WebSocketsServer.h>  
#include <ArduinoJson.h>    
#include <Preferences.h>
#include <SPIFFS.h>
#include <Wire.h>
#include <Adafruit_Sensor.h>

#define INLED 15 // LOLIN S2 MINI ONBOARD LED

#define SDA_PIN 21  //  custom I2C SDA pin
#define SCL_PIN 34  //  custom I2C SCL pin

#define BME680_ // comment if BME680 sensor is not used
#ifdef BME680_ 
  #include <Adafruit_BME680.h>
  Adafruit_BME680 bme; // BME680 sensor I2C
#endif

#define DALLAS_ // comment if  DS18B20 DALLAS TEMP SENSOR sensor is not used
#ifdef DALLAS_ 
  #include <DallasTemperature.h>
  #include <OneWire.h>
  #define ONE_WIRE_BUS 17 // 
  OneWire oneWire(ONE_WIRE_BUS);
  DallasTemperature dallas(&oneWire); // create DS18B20 sensor instance
#endif

#define SENSIRION_ // comment if SCD41x sensor is not used
#ifdef SENSIRION_
  #include <SensirionI2CScd4x.h>  
  SensirionI2CScd4x scd4x; // create sensirion sensor instance
  // https://github.com/Sensirion/arduino-i2c-scd4x
  uint16_t alt = 9; // AMSTERDAM // local altitude in meters above sea level
  uint32_t pressureCalibration;
  float tempOffset = 0.1;
  bool ascSetting = false; // Turn automatic self calibration off
#endif

#define OLED_ // comment if SSD1306 OLED displayis not used
#ifdef OLED_ 
  #include <Adafruit_GFX.h>
  #include <Adafruit_SSD1306.h>
  #define OLED_RESET 17
  #define SCREEN_WIDTH 128 
  #define SCREEN_HEIGHT 64 
  Adafruit_SSD1306 display(SCREEN_WIDTH, SCREEN_HEIGHT, &Wire, OLED_RESET);
#endif

#define NEOPIXEL_ // comment if neopixels are not used
#ifdef NEOPIXEL_
  #include <Adafruit_NeoPixel.h>
  const int neoPixelPin = 7;  
  Adafruit_NeoPixel neopixel(1, neoPixelPin, NEO_GRB + NEO_KHZ800);
#endif


#define MOTOR_
#ifdef MOTOR_
  #include <Stepper.h>
  const int stepsPerRevolution = 600;  // number of steps per revolution
  const int endstopPin = 9;  // endstop pin
  // ULN2003 Motor Driver Pins
  #define IN1 1 // 35 
  #define IN2 2 // 33 
  #define IN3 3 // 18 
  #define IN4 4 // 16 
  Stepper myStepper(stepsPerRevolution, IN1, IN3, IN2, IN4);
#endif


// sensors' global variables
uint16_t CO2 = 0;
float TEMP = 0;
float HUM = 0;
float DSTEMP = 0;
float BMETEMP = 0;
float BMEHUM = 0;
float BMEPRES= 0;
float BMEGAS= 0;

TaskHandle_t countdownTaskHandle = NULL; // countdown and sensors read timeout handler

// SPIFFS memory global variables
long int SPIFFS_TOTAL;
long int SPIFFS_USED;
long int SPIFFS_REMAINING;

// variables via websocket 
int endStop = 0; // cap is down in place
int countdown = 0; // counter for visualizing read sensors timeout 


// millis used for resetting a timestamp for the datalog json file
unsigned long startupTime;
unsigned long adjustedMillis;

Preferences preferences; // unused for esp32 internal memory prefs

// init instances of web/socket servers
AsyncWebServer server(80);
WebSocketsServer webSocket = WebSocketsServer(81);   


/////////////////////////////////
void printUint16Hex(uint16_t value) {
    Serial.print(value < 4096 ? "0" : "");
    Serial.print(value < 256 ? "0" : "");
    Serial.print(value < 16 ? "0" : "");
    Serial.print(value, HEX);
}

/////////////////////////////////
void printSerialNumber(uint16_t serial0, uint16_t serial1, uint16_t serial2) {
    Serial.print("Serial: 0x");
    printUint16Hex(serial0);
    printUint16Hex(serial1);
    printUint16Hex(serial2);
    Serial.println();
}

/////////////////////////////////
void sendJson(String l_type, String l_value) {
    String jsonString = "";
    StaticJsonDocument<200> doc;
    JsonObject object = doc.to<JsonObject>();
    object["type"] = l_type;              
    object["value"] = l_value;
    serializeJson(doc, jsonString);           
    webSocket.broadcastTXT(jsonString);
}

/////////////////////////////////
void read_prefs(){
  preferences.begin("vimo-pref", false); 
  unsigned int mot_speed = preferences.getUInt("mot_speed", 0);
  preferences.end();
}

/////////////////////////////////
void write_prefs(){
  preferences.begin("vimo-pref", false); 
  preferences.end();
}


///////////////////////////////////
void cap_Open(){
  #ifdef MOTOR_
    myStepper.step(stepsPerRevolution / 2);
  #endif
}

///////////////////////////////////
void cap_Close(){
#ifdef MOTOR_
  int count = 1;
  myStepper.step(-1*(stepsPerRevolution / 2));

  // this is useful when using an endstop 
  // while(1){
  //       // Serial.println("Signal wire is not connected to ground.");
  //       myStepper.step(-1);
  //       count++;
  //         // myStepper.step(-stepsPerRevolution);
  //       if(digitalRead(endstopPin) == LOW){ 
  //           delay(2000);
  //           return;
  //       }
  //   }
#endif

}

///////////////////////////////////
void readBME680(){

  #ifdef BME680_
      if (bme.performReading()) {
      BMETEMP = bme.temperature;
      Serial.print("Temperature: ");
      Serial.print(BMETEMP);
      Serial.println(" *C");
    
      BMEPRES = bme.pressure / 100.0;
      Serial.print("Pressure: ");
      Serial.print(BMEPRES);
      Serial.println(" hPa");
      
      BMEHUM = bme.humidity;
      Serial.print("Humidity: ");
      Serial.print(BMEHUM);
      Serial.println(" %");

      BMEGAS = bme.gas_resistance / 1000.0;
      Serial.print("Gas: ");
      Serial.print(BMEGAS);
      Serial.println(" KOhms");

      Serial.println();
    } else {
      Serial.println("Failed to read data from BME680 sensor!");
    }
  #endif

}
////////////////////////////
void dataLog(char* varname, float variable, unsigned long timestamp) {

unsigned long currentTime = timestamp;
unsigned long seconds = currentTime / 1000;
unsigned long minutes = seconds / 60;
unsigned long hours = minutes / 60;

seconds %= 60;
minutes %= 60;

String myTimeString = String(hours) + ":" + String(minutes) + ":" + String(seconds);


  if(SPIFFS_REMAINING > 20000){ // check if enough memory is left in SPIFFS (min 20k)
 
      // Open JSON log file in append mode
      File logFile = SPIFFS.open("/datalog.json", FILE_APPEND);
      if (!logFile) {
        Serial.println("Failed to open log file");
        return;
      }

      // Create JSON object
      StaticJsonDocument<100> jsonDoc;
      jsonDoc[varname] = variable;
      jsonDoc["timestamp"] = myTimeString;

      // Serialize JSON object to string
      String jsonString;
      serializeJson(jsonDoc, jsonString);

      // Append JSON string to log file
      logFile.println(jsonString);

      // Close log file
      logFile.close();

      String datastring = String(varname) + ": " + String(variable) + " " + myTimeString;
      sendJson("_COXY_DATALOG",  datastring);

   }

}

///////////////////////////////////
void SensiLog(){
      // logging SENSIRION data to datalog.json file in SPIFFS memory
      adjustedMillis = millis() - startupTime;

      unsigned long time_stamp = adjustedMillis; // using simple millis as timestamp

      dataLog("Co2",CO2, time_stamp);
      delay(100);
      dataLog("TEMP",TEMP, time_stamp);
      delay(100);
      dataLog("HUM",HUM, time_stamp);
      delay(100);
}


/////////////////////////////////
void updateWebClient(){
 
  String l_value = "";

  // WIFI SSID  
  l_value = current_SSID;
  sendJson("_SSID",  l_value);

  // WIFI IP  
  l_value = current_IP;
  sendJson("_IP",  l_value);

  #ifdef SENSIRION_
    // sensirion data
    l_value = String(CO2);
    sendJson("_CO2",  l_value);
    l_value = String(TEMP);
    sendJson("_TEMP",  l_value);
    l_value = String(HUM);
    sendJson("_HUM",  l_value);
  #endif

  #ifdef BME680_
    // bme data
    l_value = String(BMEPRES);
    sendJson("_BMEPRES",  l_value);
    l_value = String(BMETEMP);
    sendJson("_BMETEMP",  l_value);
    l_value = String(BMEHUM);
    sendJson("_BMEHUM",  l_value);
    l_value = String(BMEGAS);
    sendJson("_BMEGAS",  l_value);
  #endif

  #ifdef DALLAS_
    // DS data
    l_value = String(DSTEMP);
    sendJson("_DSTEMP",  l_value);
  #endif

  // SPIFF TOTAL memory
  l_value = String(SPIFFS_TOTAL);
  sendJson("_SPIFFS_TOTAL",  l_value);
  // SPIFF USED memory
  l_value = String(SPIFFS_USED);
  sendJson("_SPIFFS_USED",  l_value);
  // SPIFF REMAINING memory
  l_value = String(SPIFFS_REMAINING);
  sendJson("_SPIFFS_REMAINING",  l_value);

}

///////////////////////////////////
void readDallas(){
  #ifdef DALLAS_
    dallas.requestTemperatures();
    DSTEMP = dallas.getTempCByIndex(0);
  #endif
}

///////////////////////////////////
void readSensirion(){

  #ifdef SENSIRION_
    uint16_t error;
    char errorMessage[256];

    delay(100);

    // Read Measurement
    CO2= 0;
    TEMP = 0.0f;
    HUM = 0.0f;
    bool isDataReady = false;
    error = scd4x.getDataReadyFlag(isDataReady);
    if (error) {
        Serial.print("Error trying to execute getDataReadyFlag(): ");
        errorToString(error, errorMessage, 256);
        Serial.println(errorMessage);
         return;
    }
    if (!isDataReady) {
         return;
    }
    error = scd4x.readMeasurement(CO2, TEMP, HUM);
    if (error) {
        Serial.print("Error trying to execute readMeasurement(): ");
        errorToString(error, errorMessage, 256);
        Serial.println(errorMessage);
    } else if (CO2 == 0) {
        Serial.println("Invalid sample detected, skipping.");
    } else {
        Serial.print("Co2:");
        Serial.print(CO2);
        Serial.print("\t");
        Serial.print("Temperature:");
        Serial.print(TEMP);
        Serial.print("\t");
        Serial.print("Humidity:");
        Serial.println(HUM);
    }

   updateWebClient();
   #endif

}


/////////////////////////////////
void updateOLED(){

  #ifdef OLED_
    String line1 = "Co2: " + String(CO2);
    String line2 = "Temperature: " + String(TEMP);
    String line3 = "Humidity: " + String(HUM);
    
    display.clearDisplay();
    display.setCursor(0, 0);
    display.println("SENSIRION SCD41");
    display.setCursor(0, 20);
    display.println(line1);
    display.setCursor(0, 35);
    display.println(line2);
    display.setCursor(0, 50);
    display.println(line3);
    display.display();
  #endif

}


/////////////////////////////////
void webSocketEvent(byte num, WStype_t type, uint8_t * payload, size_t length) {      
  switch (type) {                                 
    
    case WStype_DISCONNECTED:  // client disconnected
      Serial.println("Client " + String(num) + " disconnected");
      // Attempt to reconnect after a short delay
      delay(2000);
      webSocket.begin();  // restart websocket
      Serial.println("Websocket server re-started");
      break;
   
    case WStype_CONNECTED:  // client connected                         
      Serial.println("Client " + String(num) + " connected");
      updateWebClient(); // update all connected clients
      break;
      
    case WStype_ERROR:
      Serial.println("WebSocket error");
      // Attempt to reconnect after a short delay
      delay(2000);
      // reSTART WEBSOCKET 
      webSocket.begin();   // restart websocket   
      Serial.println("Websocket server re-started");
      break;

    case WStype_TEXT: // if a client has sent data, do JSON decoding
      StaticJsonDocument<200> doc; 
      DeserializationError error = deserializeJson(doc, payload);
      if (error) {
        Serial.print(F("deserializeJson() failed: "));
        Serial.println(error.f_str());
        return;
      }
      else {
        const char* l_type = doc["type"];
        const int l_value = doc["value"];
        Serial.println("Type: " + String(l_type));
        Serial.println("Value: " + String(l_value));

        if(String(l_type) == "CAP_motor") {
          int motor_action = int(l_value);
          sendJson("CAP_open", String(motor_action));
          if ( motor_action == 0){
              cap_Close();
          }else if ( motor_action == 1){
              cap_Open();
          }    
        }
        
        if(String(l_type) == "REFRESH_gui") {
          updateWebClient();
        }
        

        if(String(l_type) == "SAVE_prefs") {
          write_prefs();
        }

        if(String(l_type) == "TIME_stamp") {
          // Serial.println(l_value);
          String myTS  =  String(l_value);
          Serial.print("TIMESTAMP: ");
          Serial.println(myTS);
        }

      }

      Serial.println("");
      break;
  }
}




/////////////////////////////////
void check_SPIFFS(){

  // Calculate total space
  SPIFFS_TOTAL = SPIFFS.totalBytes();
  Serial.print("Total space: ");
  Serial.print(SPIFFS_TOTAL);
  Serial.println(" bytes");

  // Calculate used space
  SPIFFS_USED = SPIFFS.usedBytes();
  Serial.print("Used space: ");
  Serial.print(SPIFFS_USED);
  Serial.println(" bytes");

  // Calculate free space
  SPIFFS_REMAINING = SPIFFS_TOTAL - SPIFFS_USED;
  Serial.print("Free space: ");
  Serial.print(SPIFFS_REMAINING);
  Serial.println(" bytes");
  
  String l_value = "";

  // SPIFF TOTAL memory
  l_value = String(SPIFFS_TOTAL);
  sendJson("_SPIFFS_TOTAL",  l_value);
  // SPIFF USED memory
  l_value = String(SPIFFS_USED);
  sendJson("_SPIFFS_USED",  l_value);
  // SPIFF REMAINING memory
  l_value = String(SPIFFS_REMAINING);
  sendJson("_SPIFFS_REMAINING",  l_value);

}

////////////////////////////
void list_SPIFFS(){  
  // Open the directory
  File root = SPIFFS.open("/");
  File file = root.openNextFile();

  // Create a file to store the file list
  File fileList = SPIFFS.open("/fileList.txt", FILE_WRITE);

  if (!fileList) {
    Serial.println("Failed to create fileList.txt");
    return;
  }

  while (file) {
    // Collect file names and sizes and write to the fileList.txt
    fileList.print(file.name());
    fileList.print(" ");
    fileList.println(file.size());
    Serial.print("Name: ");
    Serial.print(file.name());
    Serial.print(", Size: ");
    Serial.println(file.size());
    file = root.openNextFile();
  }
  // Close the fileList.txt
  fileList.close();
  Serial.println("File list generation completed");
  sendJson("_SPIFFS_FILELIST",  "");
  file.close(); 
  root.close();
}

////////////////////////////
void initDataLog(){
    // Remove the existing data.json file
  if (SPIFFS.exists("/datalog.json")) {
    SPIFFS.remove("/datalog.json");
    Serial.println("Removed existing datalog.json file");
  }

  // Create a new data.json file
  File file = SPIFFS.open("/datalog.json", "w");
  if (!file) {
    Serial.println("Failed to create datalog.json");
    return;
  }else{
     Serial.println("Created new datalog.json file");
  }
  file.close();
}

//////////////////////////////
void updateWIFI(){
  sendJson("_SSID",  current_SSID);
  sendJson("_IP",  current_IP);
}

///////////////////////////////////
void countdownTask(void *arg) {
  while(1){

      if(countdown >= 0){
        countdown--; // Decrement the countdown value
        String l_value = ""; 
        l_value = String(countdown);
        sendJson("_COUNTDOWN",  l_value);
      }else{
        countdown = 30;

      updateWIFI();
      check_SPIFFS();
      list_SPIFFS();
      SensiLog();

      #ifdef SENSIRION_
        readSensirion();
      #endif
       
      #ifdef OLED_ 
        updateOLED();
      #endif 

      #ifdef BME680_
        readBME680();
      #endif 

      #ifdef DALLAS_
         readDallas();
      #endif  

      }
  
    long int intervallo = 1 * 1000; // 1 second interval
    vTaskDelay(intervallo / portTICK_RATE_MS);
  }

}

///////////////////////////////////
void setup() {

  Serial.begin(115200);

  pinMode(LED_BUILTIN, OUTPUT);

  startupTime = millis(); // Store the startup time

   #ifdef MOTOR_
    pinMode(endstopPin, INPUT_PULLUP); // end_switch pin
   #endif


 // Connect to a known WiFi network if available
  connectToWiFi();
  // If not connected, create an Access Point
  if (WiFi.status() != WL_CONNECTED) {
    createAccessPoint();
  }else{
    #ifdef NEOPIXEL_
    for(int i=1; i<=3; i++){
      neopixel.setPixelColor(0, neopixel.Color(0, 0, 200)); 
      neopixel.show();
      delay(250);
      neopixel.setPixelColor(0, neopixel.Color(0, 0, 0)); 
      neopixel.show();
      delay(250);
      #endif
    }
  }

  server.on("/", HTTP_GET, [](AsyncWebServerRequest * request) {
      request->send(SPIFFS, "/index.html", "text/html");
    });

  server.on("/style.css", HTTP_GET, [](AsyncWebServerRequest *request){
      request->send(SPIFFS, "/style.css", "text/css");
  });

  server.on("/favicon.ico", HTTP_GET, [](AsyncWebServerRequest *request){
      request->send(SPIFFS, "/favicon.ico", "image/x-icon");
  });

  server.on("/coxy.js", HTTP_GET, [](AsyncWebServerRequest *request){
      request->send(SPIFFS, "/coxy.js", "text/javascript");
  });

  server.on("/highcharts.js", HTTP_GET, [](AsyncWebServerRequest *request){
      request->send(SPIFFS, "/highcharts.js", "text/javascript");
  });

  server.on("/fileList.txt", HTTP_GET, [](AsyncWebServerRequest *request){
      request->send(SPIFFS, "/fileList.txt", "text/plain");
  });


  server.on("/lighting.png", HTTP_GET, [](AsyncWebServerRequest *request){
      request->send(SPIFFS, "/lighting.png", "image/png");
  });

  server.on("/transpix.png", HTTP_GET, [](AsyncWebServerRequest *request){
      request->send(SPIFFS, "/transpix.png", "image/png");
  });

  server.on("/trilogoz.png", HTTP_GET, [](AsyncWebServerRequest *request){
      request->send(SPIFFS, "/trilogoz.png", "image/png");
  });

  server.on("/glassdisplay.png", HTTP_GET, [](AsyncWebServerRequest *request){
      request->send(SPIFFS, "/glassdisplay.png", "image/png");
  });
  
  server.on("/origami.ttf", HTTP_GET, [](AsyncWebServerRequest *request){
      request->send(SPIFFS, "/origami.ttf", "font/ttf");
  });

  server.on("/cons.ttf", HTTP_GET, [](AsyncWebServerRequest *request){
      request->send(SPIFFS, "/cons.ttf", "font/ttf");
  });

    server.on("/datalog.json", HTTP_GET, [](AsyncWebServerRequest *request){
      request->send(SPIFFS, "/datalog.json", "application/json");
  });


  // Start server
  server.begin();
  Serial.println("HTTP server started");

  // START WEBSOCKET 
  webSocket.begin();                                  // start websocket
  webSocket.onEvent(webSocketEvent);                  // define a callback function -> what does the ESP32 need to do when an event from the websocket is received? -> run function "webSocketEvent()"
  Serial.println("Websocket server started");

  // START I2C communication 
  Wire.begin(SDA_PIN, SCL_PIN); 

  // INIT NEOPIXEL 
  #ifdef NEOPIXEL_
    neopixel.setPixelColor(0, neopixel.Color(200, 0, 0)); 
    neopixel.show();
  #endif

 // INIT MOTOR 
 #ifdef MOTOR_
   myStepper.setSpeed(10); 
 #endif

 // INIT DS18B20 TEMP SENSOR 
  #ifdef DALLAS_
    dallas.begin(); // DS18B20 temp. sensor begin
  #endif

// INIT SENSIRION SCD4x SENSOR 
 #ifdef SENSIRION_
     uint16_t error;
    char errorMessage[256];

    scd4x.begin(Wire); // Initialize SENSIRION sensor 
  
    scd4x.setSensorAltitude(alt); //  altitude in meters above sea level.
    //scd4x.setAmbientPressure(pressureCalibration); // 
    scd4x.setTemperatureOffset(tempOffset);
    scd4x.setAutomaticSelfCalibration(ascSetting);
    
    uint16_t ascEnabled;
    error = scd4x.getAutomaticSelfCalibration(ascEnabled);
    if (error) {
        Serial.print("Error trying: ");
        errorToString(error, errorMessage, 256);
        Serial.println(errorMessage);
    } else {
        Serial.print("AutoSelfCalibrations is: ");
        if (ascEnabled) Serial.println("ON");
        if (!ascEnabled) Serial.println("OFF");
    }
    
    uint16_t setAlt;
    error = scd4x.getSensorAltitude(setAlt);
    if (error) {
        Serial.print("Error trying: ");
        errorToString(error, errorMessage, 256);
        Serial.println(errorMessage);
    } else {
        Serial.print("Altitude is set to: ");
        Serial.println(setAlt);
    }

    float settempOffset;
    error = scd4x.getTemperatureOffset(settempOffset);
    if (error) {
        Serial.print("Error trying: ");
        errorToString(error, errorMessage, 256);
        Serial.println(errorMessage);
    } else {
        Serial.print("Temperature Offset set to: ");
        Serial.println(settempOffset);
    }
    

    // stop potentially previously started measurement
    error = scd4x.stopPeriodicMeasurement();
      if (error) {
          Serial.print("Error trying to execute stopPeriodicMeasurement(): ");
          errorToString(error, errorMessage, 256);
          Serial.println(errorMessage);
      }

    uint16_t serial0;
    uint16_t serial1;
    uint16_t serial2;
    error = scd4x.getSerialNumber(serial0, serial1, serial2);
    if (error) {
        Serial.print("Error trying to execute getSerialNumber(): ");
        errorToString(error, errorMessage, 256);
        Serial.println(errorMessage);
      } else {
          printSerialNumber(serial0, serial1, serial2);
      }

    // Start Measurement
    error = scd4x.startPeriodicMeasurement();
      if (error) {
          Serial.print("Error trying to execute startPeriodicMeasurement(): ");
          errorToString(error, errorMessage, 256);
          Serial.println(errorMessage);
      }

    Serial.println("Waiting for first measurement... (5 sec)");

    delay(5000);

      #ifdef NEOPIXEL_
      neopixel.setPixelColor(0, neopixel.Color(200, 200, 0)); 
      neopixel.show();
      #endif

     

#endif

// INIT BME680 sensor
#ifdef BME680_
    if (!bme.begin()) {
      Serial.println("Could not find BME680 sensor!");
      while (1);
    }
    Serial.println("BME680 sensor found!");
    readBME680();
#endif
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
void loop() {
  webSocket.loop(); 
}

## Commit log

2024-03-15 update pcb photos
2024-03-16 stl update
    [CoxyBoxy-Top.stl, CoxyBoxy.stl, USBC-12mm-Holder.stl]
2024-03-19 co2y pcb gerber
    [CO2Y-brkout-B_Cu.gbr, CO2Y-brkout-B_Mask.gbr, CO2Y-brkout-B_Silkscreen.gbr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]
